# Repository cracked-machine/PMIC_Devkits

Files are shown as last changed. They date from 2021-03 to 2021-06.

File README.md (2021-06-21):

# <U>STPMIC1 / PF3000 PMIC Dev Board</U>

#### Overview

Dual development board for evaluating two power management integrated circuits (PMIC) chips:

- STMicroElectronics STPMIC1
- NXP PF3000 Power Management ICs.

These are organised into two independantly powered sub-systems.

Each sub-system has a number of external power/signal connectors, along with a list of the jumpers used to configure how those connectors are routed to/from the PMIC chip. The PMICs are configured directly by modifying registers using either a MCU/MPU via the I2C connectors.

Each output has an LED indicator and testpoint. 
_Note_ that the LED will only light if the PMIC output voltage is set above 2V.

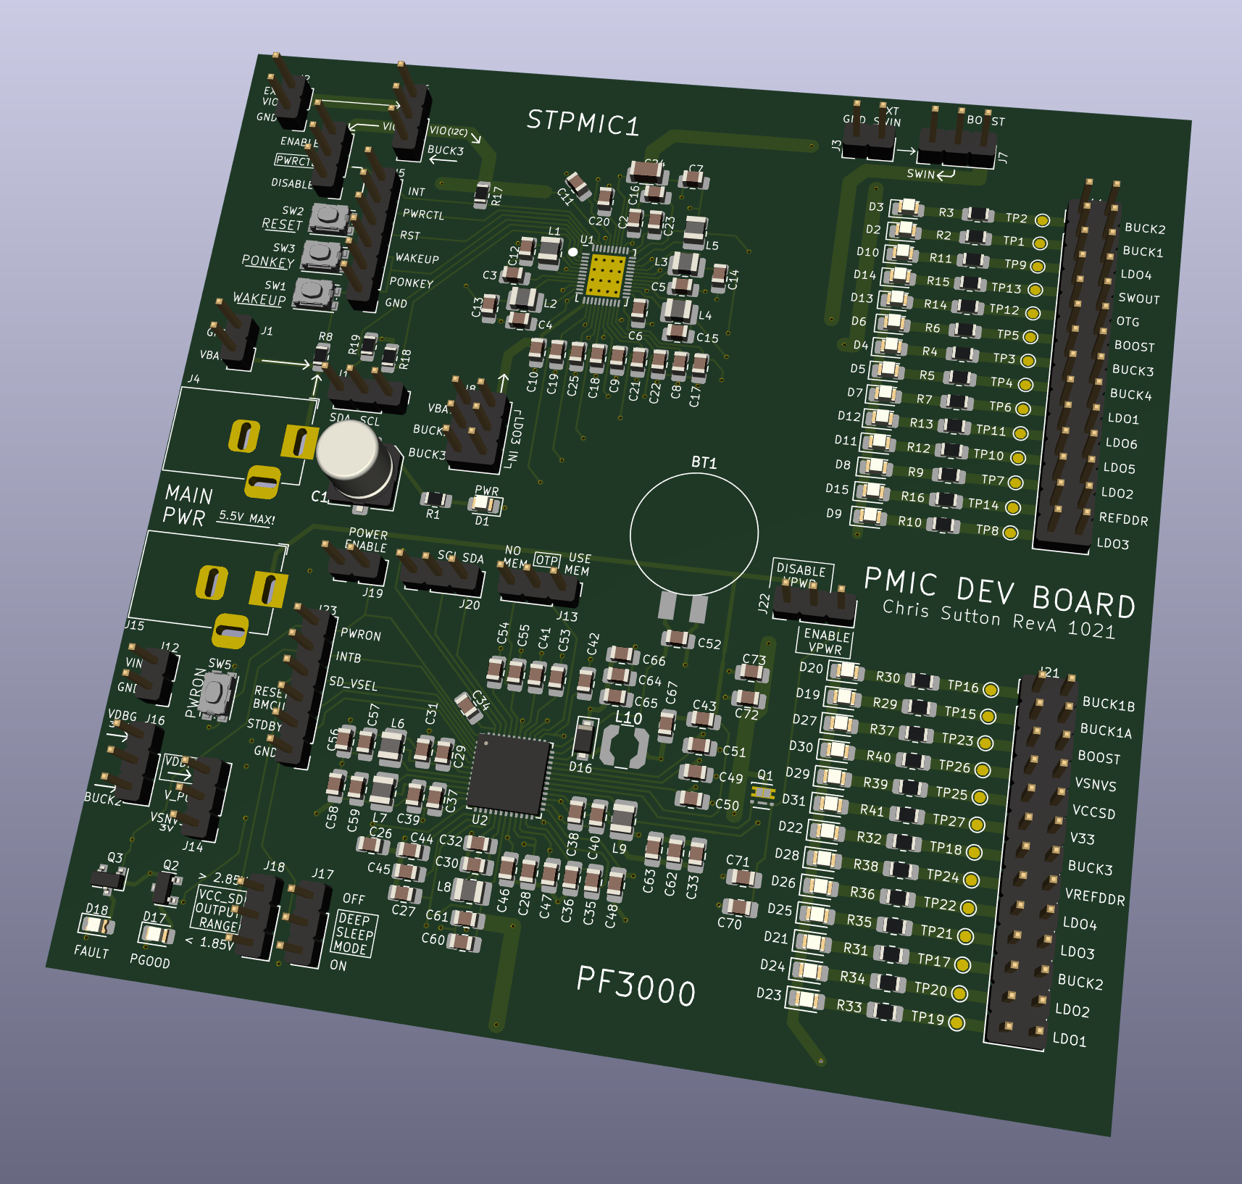
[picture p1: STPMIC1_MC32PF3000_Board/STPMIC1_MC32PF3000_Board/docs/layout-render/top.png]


#### Circuit design notes
The schematic has a separate sheet for both sub-systems. There is one for each chip: 

- __DEV__ - The development board sub-system including power/config connectors.
- __MAIN__ - The individual PMIC including the required passive components for bypassing and SMPS/regulator operation. Designed to be reuseable blocks that can easily be incorproated into an existing design.

| STPMIC1 DEV | STPMIC1 MAIN |
|:---:|:---:|
||

| PF3000 DEV | PF3000 MAIN  |
|:---:|:---:|
|||

#### PCB layout notes
This is a four layer PCB design. The layer stackup is:

1. Signal
2. Ground
3. Small signal and power
4. Small signal and ground

Note the ground planes in layer 2 and 4 are connected.

The _docs_ directory contains:
- RevA gerber build files.
- [Bill of Materials](STPMIC1_MC32PF3000_Board/STPMIC1_MC32PF3000_Board/docs/bom/FULL_STPMIC1_MC32PF3000_Board.csv)
- CPL pick and place files.
- Related vendor application notes, datasheets and reference designs.

Custom symbols and footprints used in this project can be found in the [KicadLibrary](https://github.com/cracked-machine/KicadLibrary) repository.

## <U>PMIC #1: NXP PF300</U>

#### <U>Board connector definitions</U>

| Connector | Description | Comment |
|:---:|:---:|:---|
|J15|Wall adaptor power input|3.7V - 5.5V<br>DC Barrel 2.1mm|
|J12|Battery power input|3.1V - 4.5V<br>2.54mm Header|
|J20|I2C debug|1: Ground<br>2: SCL<br>3: SDA|
|J23|Digital Interface<br>(see datasheet)|1: Ground<br>2: STANDBY<br>3: RESETBMCU<br>4: SD_VSEL<br>5: INTB<br>6: PWRON|
|J21|PF3000 Power Output|Ground:<br>2,4,6,8,10,12,14,16,18,20,22,24,26<br><br>1: SW1B Buck <br>3: SW1A Buck <br>5: SWBST Boost<br>7: VSNVS LDO<br>9: VCCSD LDO<br>11: V33 LDO<br> 13: SW3 Buck<br>15: VREFDDR LDO<br>17: LDO4<br> 19: LDO3<br>21: SW2 Buck<br>23: LDO2<br> 25: LDO1

#### <U>Board jumper and switch definitions</U>

Warning: function of jumpers can be inverted using the registers. See datasheet for details.

| Jumper/Switch | Description| Setting | Comment |
|:---:|:---:|:---:|:---|
|JP1|Q2 Pullup|ON|Force Q2 gate to VDBG rail. <br>Use if PGOOD LED becomes erratic.|
|JP2|Q3 Pullup|ON|Force Q3 to VDBG rail. <br>Use if FAIL LED becomes erratic.|
|J13|OTP|3-2|Load OTP values from memory into OTP registers|
|J13|OTP|2-1|Disable OTP memory and load OTP values from fuses. "Try before buy" mode.|
|J16|I2C Bus Power (VDDIO)|3-2|Power from VDGB. 3.3V|
|J16|I2C Bus Power (VDDIO)|2-1|Power from Buck 2 output. 1.8V|
|J14|Digital Interface Power (V_PU)|3-2|Power from J16 output|
|J14|Digital Interface Power (V_PU)|2-1|Power from VSNVS output (fixed 3V)|
|J17|Standby|3-2|Enter standby mode|
|J17|Standby|2-1|Exit standby mode|
|J18|VCC_SD output range|3-2|1.8V to 1.85V|
|J18|VCC_SD output range|2-1|2.85V to 3.3V|
|J19|Power enable|2-1|IC power output is enabled|
|SW5|Power enable| - | Momentary SPST.<br>IC power output is enabled.
|J22|VPWR override|3-2|VPWR enable. <br>Set when J15 DC connector is powered|
|J22|VPWR override|2-1|VPWR disable. <br>Set when J12 battery power connector is powered.<br>Warning: Shorts J15 to ground!|

## <U>PMIC #2: STMicroelectronics STPMIC1</U>

#### <U>Board connector definitions</U>

| Connector | Description | Comment |
|:---:|:---:|:---|
|J2|External VIO|0.5V to 4.2V.<br>I/O voltage (for all digital signals except WAKEUP and PONKEY)|
|J3|External SWIN|0.5V - 7V.<br>External power source for VSWIN pin.
|J4|Wall adaptor power input|0.5V - 7V.<br>DC Barrel 2.1mm|
|J1|Battery power input|0.5V - 7V.<br>2.54mm Header|
|J10|I2C debug|1: Ground<br>2: SCL<br>3: SDA|
|J5|Digital Interface<br>(see datasheet)|1: Ground<br>2: PONKEY (IN)<br>3: WAKEUP (IN)<br>4: RST (BOTH)<br>5: PWRCTL (IN)<br>6: INT (OUT)|
|J21|STPMIC1 Power Output|Ground:<br>2,4,6,8,10,12,14,16,18,20,22,24,26<br><br>1: Buck2 <br>3: Buck1 <br>5: LDO4<br>7: VSWOUT LDO<br>9: VOTG LDO<br>11: Boost<br> 13: Buck3<br>15: Buck4<br>17: LDO1<br> 19: LDO6<br>21: LDO5<br>23: LDO2<br> 25: VREFDDR LDO<br>27: LDO3|

#### <U>Board jumper and switch definitions</U>

Warning: function of jumpers can be inverted using the registers. See datasheet for details.

| Jumper/Switch | Description| Setting | Comment |
|:---:|:---:|:---:|:---|
|J6|VIO source select|3-2|Power source from Buck3 output|
|J6|VIO source select|2-1|Power source from VIO Ext (J2)|
|J7|VSWIN source select|3-2|Power source from BOOST output|
|J7|VSWIN source select|2-1|Power source from SWIN Ext (J3)|
|J8|LDO3 source select|1-2|Power source from VBAT (J4 or J1)|
|J8|LDO3 source select|3-4|Power source from BUCK2 output|
|J8|LDO3 source select|5-6|Power source from BUCK2 output|
|J9|PWRCTL Pullup/Pulldown|3-2|Pullup from VIO (J6)|
|J9|PWRCTL Pullup/Pulldown|2-1|Pulldown to ground|
|SW1|Wakeup enable| - |Momentary SPST to VBAT|
|SW2|IC Reset| - |Momentary SPST to ground|
|SW3|PONKEY| - |User power on key|

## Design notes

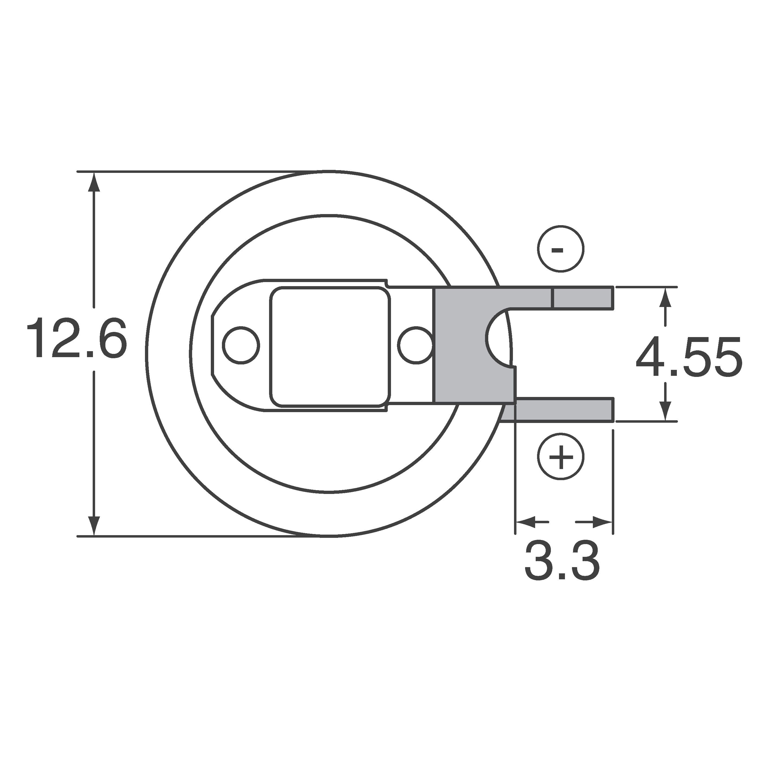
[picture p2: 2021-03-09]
STPMIC1_MC32PF3000_Board/STPMIC1_MC32PF3000_Board/docs/Datasheets/Panasonic - ML-1220 F1BN - 3 Volt 17mAh Lithium.jpg

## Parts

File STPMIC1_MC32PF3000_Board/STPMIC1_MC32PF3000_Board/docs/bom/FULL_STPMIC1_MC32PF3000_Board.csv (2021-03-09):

Reference | Quantity | Value | Footprint | Datasheet | LCSC | MfrNum | Mouser | Type
BT1 | 1 | Battery_Cell | Panasonic_ML_series:ML1220_F1BN | https://docs.rs-online.com/ea3f/0900766b816cd421.pdf | ~ | ML-1220/F1BN | ~ | Panasonic 3V Lithium Manganese Dioxide Button Rechargeable Battery, 17mAh
C1 | 1 | 100uF | Capacitor_SMD:C_Elec_6.3x7.7 | ~ | C127971 | ~ | ~ | ~
C12 C13 C14 C15 C16 C44 C46 C49 C56 C57 C58 C59 C60 C61 C62 C63 C64 C65 C72 C73 | 20 | 22uF | Capacitor_SMD:C_0805_2012Metric_Pad1.18x1.45mm_HandSolder | ~ | C45783 | CL21A226MPQNNNE | ~ | CAP CER 22uF 25V 20% X5R 0805
C2 C11 C17 C18 C20 C21 C22 C23 C43 C45 C47 C50 | 12 | 4.7uF | Capacitor_SMD:C_0805_2012Metric_Pad1.18x1.45mm_HandSolder | ~ | C1779 | ~ | ~
C3 C4 C5 C6 C7 C10 C19 C29 C30 C37 C38 C42 C67 C69 | 14 | 10uF | Capacitor_SMD:C_0805_2012Metric_Pad1.18x1.45mm_HandSolder | ~ | C15850 | ~ | ~
C24 | 1 | 220uF | Capacitor_SMD:C_1206_3216Metric_Pad1.33x1.80mm_HandSolder | ~ | ~ | ~ | ~ | ~
C8 C9 C25 C26 C27 C28 C33 C41 C48 C53 C55 C68 | 12 | 1uF | Capacitor_SMD:C_0805_2012Metric_Pad1.18x1.45mm_HandSolder | ~ | C28323 | ~ | ~
C31 C32 C34 C35 C36 C39 C40 | 7 | 100nF | Capacitor_SMD:C_0805_2012Metric_Pad1.18x1.45mm_HandSolder | ~ | C49678 | ~ | ~ | ~
C51 | 1 | 470nF | Capacitor_SMD:C_0805_2012Metric_Pad1.18x1.45mm_HandSolder | ~ | C13967 | ~ | ~ | ~
C52 C54 | 2 | 220nF | Capacitor_SMD:C_0805_2012Metric_Pad1.18x1.45mm_HandSolder | ~ | C5378 | ~ |  | CAP CER 0.22UF 16V 10% X7R 0402
C66 | 1 | 10nF | Capacitor_SMD:C_0805_2012Metric_Pad1.18x1.45mm_HandSolder | ~ | C1710 | ~ | ~ | ~
C70 C71 | 2 | 47uF | Capacitor_SMD:C_0805_2012Metric_Pad1.18x1.45mm_HandSolder | ~ | C16780 | C2012X5R1A476M125AC | ~ | CAP CER 47uF 10V 20% X5R 0805
D1 D2 D3 D4 D5 D6 D7 D8 D9 D10 D11 D12 D13 D14 D15 D19 D20 D21 D22 D23 D24 D25 D26 D27 D28 D29 D30 D31 | 28 | D | LED_SMD:LED_0805_2012Metric_Pad1.15x1.40mm_HandSolder | ~ | C84256 | ~ | ~ | ~
D16 | 1 | MBR120LSFT3G | Diode_SMD:D_SOD-123F | https://www.mouser.co.uk/datasheet/2/281/product-1023514.pdf | C190475 | ~ | ~ | ~
D17 | 1 | PGOOD | LED_SMD:LED_0805_2012Metric_Pad1.15x1.40mm_HandSolder | ~ | C84256 | ~ | ~ | ~
D18 | 1 | FAULT | LED_SMD:LED_0805_2012Metric_Castellated | ~ | C84256 | ~ | ~ | ~
J6 J7 J9 J10 J13 J14 J16 J17 J18 J20 J22 | 11 | Conn_01x03 | Connector_PinHeader_2.54mm:PinHeader_1x03_P2.54mm_Vertical | ~ | ~ | ~ | ~ | ~
J11 | 1 | Conn_02x14_Odd_Even | Connector_PinHeader_2.54mm:PinHeader_2x14_P2.54mm_Vertical | ~ | ~ | ~ | ~ | ~
J15 | 1 | Barrel_Jack_Switch | Connector_BarrelJack:BarrelJack_Horizontal | ~ | ~ | ~ | ~ | ~
J21 | 1 | Conn_02x13_Odd_Even | Connector_PinHeader_2.54mm:PinHeader_2x13_P2.54mm_Vertical | ~ | ~ | ~ | ~ | ~
J1 J2 J3 J12 J19 | 5 | Conn_01x02 | Connector_PinHeader_2.54mm:PinHeader_1x02_P2.54mm_Vertical | ~ | ~ ~ ~ ~ ~ ~ ~ ~ ~ ~ | ~ | ~ | ~
J4 | 1 | Barrel_Jack | Connector_BarrelJack:BarrelJack_Horizontal | ~ | ~ | ~ | ~ | ~
J5 J23 | 2 | Conn_01x06 | Connector_PinHeader_2.54mm:PinHeader_1x06_P2.54mm_Vertical | ~ | ~ | ~ | ~ | ~
J8 | 1 | Conn_02x03_Odd_Even | Connector_PinHeader_2.54mm:PinHeader_2x03_P2.54mm_Vertical | ~ | ~ | ~ | ~ | ~
JP1 JP2 | 2 | Jumper_NO_Small | Jumper:SolderJumper-2_P1.3mm_Open_RoundedPad1.0x1.5mm | ~ | ~ | ~ | ~ | ~
L1 L2 L3 L4 L5 | 5 | 1uH | Inductor_SMD:L_1008_2520Metric_Pad1.43x2.20mm_HandSolder | https://www.mouser.co.uk/datasheet/2/281/product-1023391.pdf~ | ~ | DFE252012P-1R0M=P2 | 81-DFE252012P-1R0MP2 | IND PWR 1.0μH, 3.5A, 42mΩ 1008
L10 | 1 | 2.2uH | Inductor_SMD:L_Coilcraft_LPS4018 | https://www.mouser.co.uk/datasheet/2/597/lps3015-270734.pdf | ~ | LPS3015-222MRB | 994-LPS4018-222MRC | IND PWR 2.2UH@100KHZ 2.0A 20% SMT
L6 L7 L8 L9 | 4 | 1.5uH | Inductor_SMD:L_1008_2520Metric_Pad1.43x2.20mm_HandSolder | https://www.mouser.co.uk/datasheet/2/281/product-1023514.pdf | ~ | DFE252012P-1R5M=P2 | 81-DFE252012P-1R5MP2 | IND PWR 1.5uH@1MHz 3.5A 20% 1008
NT1 NT2 NT3 NT4 NT5 NT6 NT7 NT8 NT9 NT10 NT11 NT12 NT13 NT14 | 14 | Net-Tie_2 | TinyNetTies:NetTie-2_SMD_Pad0.254mm | ~ | ~ | ~ | ~ | ~
Q1 | 1 | FDMA908PZ | Package_TO_SOT_SMD:Vishay_PowerPAK_SC70-6L_Single | https://www.mouser.co.uk/datasheet/2/308/FDMA908PZ-D-1807576.pdf | ~ | ~ | 512-FDMA908PZ | PMOS PowerTrench -12V, -12A, 12.5mΩ MicroFET-6
Q2 Q3 | 2 | Q_PMOS_GSD | Package_TO_SOT_SMD:SOT-23 | https://www.onsemi.com/pdf/datasheet/ntr1p02t1-d.pdf | ~ | NTR1P02LT3G | 863-NTR1P02LT1G | ~
R1 R2 R3 R4 R5 R6 R7 R8 R9 R10 R11 R12 R13 R14 R15 R16 R18 R19 R27 R28 R29 R30 R31 R32 R33 R34 R35 R36 R37 R38 R39 R40 R41 | 33 | 2K2 | Resistor_SMD:R_0805_2012Metric_Pad1.20x1.40mm_HandSolder | ~ | C17520 | ~ | ~ | ~
R17 | 1 | 10K | Resistor_SMD:R_0805_2012Metric_Pad1.20x1.40mm_HandSolder | ~ | C17414 | ~ | ~ | ~
R20 R21 | 2 | 4K7 | Resistor_SMD:R_0805_2012Metric_Pad1.20x1.40mm_HandSolder | ~ | C17414 | ~ | ~ | ~
R22 R23 R24 R25 R26 | 5 | 100K | Resistor_SMD:R_0805_2012Metric_Pad1.20x1.40mm_HandSolder | ~ | C17407 | ~ | ~ | ~
SW1 SW2 SW3 SW5 | 4 | SW_SPST | Button_Switch_SMD:SW_Push_1P1T_NO_CK_KMR2 | https://docs.rs-online.com/fe48/0900766b815a8e8e.pdf | ~ | KMR221NGLFS | 611-KMR221NGLFS | Tactile Microminiature SMT Top Actuated
TP1 TP2 TP3 TP4 TP5 TP6 TP7 TP8 TP9 TP10 TP11 TP12 TP13 TP14 TP15 TP16 TP17 TP18 TP19 TP20 TP21 TP22 TP23 TP24 TP25 TP26 TP27 | 27 | TestPoint | TestPoint:TestPoint_Pad_D1.0mm | ~ | ~ | ~ | ~ | ~
U1 | 1 | STPMIC1 | STPMIC1:WQFN-44L_EP_5x6_Pitch0.4mm | https://www.mouser.co.uk/datasheet/2/389/stpmic1-1621294.pdf |  | STPMIC1APQR | 511-STPMIC1APQR | ~
U2 | 1 | PF3000 | Package_DFN_QFN:QFN-48-1EP_7x7mm_P0.5mm_EP5.3x5.3mm_ThermalVias | https://www.nxp.com/docs/en/data-sheet/PF3000.pdf |  | MC32PF3000A8EP | 841-MC32PF3000A8EP | ~
U3 | 1 | SE8233X2 | Package_TO_SOT_SMD:SOT-23 | https://datasheet.lcsc.com/szlcsc/1912111437_Seaward-Elec-SE8233X2_C437587.pdf | C437587 | SE8233X2 | ~ | ~

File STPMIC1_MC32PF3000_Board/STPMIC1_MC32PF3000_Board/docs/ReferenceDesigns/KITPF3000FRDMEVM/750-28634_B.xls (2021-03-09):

Level | Number | Subclass | Description | Families | Part Category | Lifecycle Phase | Rev | Rev Release Date | Rev Incorp Date | Effectivity Start Date | Exclude from Rollup | Compliance Calculated Date | Overall Compliance | Shippable Item | N/A | Commodity | Sites | BOM.Rev | BOM.Item Description | BOM.Alt Num | BOM.Find Num | BOM.Priority | BOM.Qty | BOM.Sites | BOM.Pack Slip | BOM.Ref Des | BOM.Item Type | BOM.Lifecycle Phase | BOM.Assembly Flow ID | BOM.Customer Code | BOM.BOM Notes | Manufacturers.Mfr Name ~ Location | Manufacturers.Mfr. Part Number | Manufacturers.Mfr Part Status | Manufacturers.Preferred Status | Manufacturers.Summary Compliance | Manufacturers.Mfr. Part Description | Manufacturers.Sites | Manufacturers.Reference Notes | Manufacturers.Expiry Date | Manufacturers.Supplier | Manufacturers.Qual Status
0 | 750-28634 | Part | SUB ASSEMBLY, SCHEMATIC PARTS, 700-28634, KITPF3000FRDMEVM | Analog |  | Production | B ECO56462 | 02/20/2015 06:15:38 PM CST |  |  | No | 05/08/2015 09:00:52 PM CDT | Non-Compliant | No |  |  | 5150~Freescale HW/SW MFG Austin~DEVTOOL;5154~Freescale HW/SW MFG Israel~DEVTOOL;5151~Freescale HW/SW MFG HKG~DEVTOOL;5155~Freescale HW/SW MFG HKG DWG~DEVTOOL
1 | 150-30114 | CADPart | CAP CER 0.01UF 50V 10% X7R 0402 | Special Customer Request | Component, Procured by Contract House | Production | A1 MCO34749 | 08/07/2014 06:50:43 PM CDT |  |  | No | 05/08/2015 09:00:52 PM CDT | Missing Info | No |  | Capacitor | 5150~Freescale HW/SW MFG Austin~DEVTOOL;5154~Freescale HW/SW MFG Israel~DEVTOOL;5151~Freescale HW/SW MFG HKG~DEVTOOL;5155~Freescale HW/SW MFG HKG DWG~DEVTOOL | A1 MCO34749 | CAP CER 0.01UF 50V 10% X7R 0402 | 1 | 0 | 1 | 1 |  | No | C38 | CADPart | Production |  |  |  | VENKEL COMPANY | C0402X7R500-103KNE | ROHS Active | Alternate | Missing Info | CAP CER 0.01UF 50V 10% X7R 0402
 |  |  |  |  |  |  |  |  |  |  |  |  |  |  |  |  |  |  |  |  |  |  |  |  |  |  |  |  |  |  |  | SKYMOS | 0402B103K500NT | ROHS Active | Alternate | Missing Info | CAP CER 0.01UF 50V 10% X7R 0402
 |  |  |  |  |  |  |  |  |  |  |  |  |  |  |  |  |  |  |  |  |  |  |  |  |  |  |  |  |  |  |  | WALSIN TECHNOLOGY CORP. | 0402B103K500CT | Active | Alternate | Missing Info | CAP CER 0.01UF 50V 10% X7R 0402
 |  |  |  |  |  |  |  |  |  |  |  |  |  |  |  |  |  |  |  |  |  |  |  |  |  |  |  |  |  |  |  | MURATA | GRM155R71H103KA88D | ROHS Active | Alternate | Missing Info | CAP CER 0.01UF 50V 10% X7R 0402
 |  |  |  |  |  |  |  |  |  |  |  |  |  |  |  |  |  |  |  |  |  |  |  |  |  |  |  |  |  |  |  | SAMSUNG | CL05B103KB5NNNC | Active | Alternate | Missing Info | CAP CER 0.01UF 50V 10% X7R 0402
 |  |  |  |  |  |  |  |  |  |  |  |  |  |  |  |  |  |  |  |  |  |  |  |  |  |  |  |  |  |  |  | KEMET | C0402C103K5RACTU | ROHS Active | Alternate | Missing Info | CAP CER 0.01UF 50V 10% X7R 0402
 |  |  |  |  |  |  |  |  |  |  |  |  |  |  |  |  |  |  |  |  |  |  |  |  |  |  |  |  |  |  |  | KEMET | C0402C103K5RAC | Active | Alternate | Missing Info | CAP CER 0.01UF 50V 10% X7R 0402
1 | 150-30124 | CADPart | CAP CER 1.0UF 16V 10% X5R 0603 |  | Component, Procured by Contract House | Production | A MCO34884 | 08/10/2014 07:28:07 PM CDT |  |  | No | 05/08/2015 09:00:52 PM CDT | Missing Info | No |  | Capacitor | 5150~Freescale HW/SW MFG Austin~DEVTOOL;5154~Freescale HW/SW MFG Israel~DEVTOOL;5151~Freescale HW/SW MFG HKG~DEVTOOL;5155~Freescale HW/SW MFG HKG DWG~DEVTOOL | A MCO34884 | CAP CER 1.0UF 16V 10% X5R 0603 | 1 | 0 | 1 | 2 |  | No | C3,C6 | CADPart | Production |  |  |  | TDK | C1608X5R1C105K | ROHS Active | Preferred | Missing Info | CAP CER 1.0UF 16V 10% X5R 0603
1 | 150-75283 | CADPart | CAP CER 10UF 16V 10% X5R 0805 |  | Component, Procured by Contract House | Production | A MCO34828 | 08/08/2014 04:04:37 PM CDT |  |  | No | 05/11/2015 09:06:56 AM CDT | Missing Info | No |  | Capacitor | 5150~Freescale HW/SW MFG Austin~DEVTOOL;5154~Freescale HW/SW MFG Israel~DEVTOOL;5151~Freescale HW/SW MFG HKG~DEVTOOL;5155~Freescale HW/SW MFG HKG DWG~DEVTOOL | A MCO34828 | CAP CER 10UF 16V 10% X5R 0805 | 1 | 0 | 1 | 3 |  | No | C64,C66,C69 | CADPart | Production |  |  |  | WALSIN TECHNOLOGY CORP. | 0805X106K160CT | ROHS Active | Alternate | Missing Info | CAP CER 10UF 16V 10% X5R 0805
 |  |  |  |  |  |  |  |  |  |  |  |  |  |  |  |  |  |  |  |  |  |  |  |  |  |  |  |  |  |  |  | TDK | C2012X5R1C106K/1.25 | Active | Alternate | Missing Info | CAP CER 10UF 16V 10% X5R 0805
 |  |  |  |  |  |  |  |  |  |  |  |  |  |  |  |  |  |  |  |  |  |  |  |  |  |  |  |  |  |  |  | KYOCERA | CM21X5R106K16AT | Active | Alternate | Missing Info | CAP CER 10UF 16V 10% X5R 0805
 |  |  |  |  |  |  |  |  |  |  |  |  |  |  |  |  |  |  |  |  |  |  |  |  |  |  |  |  |  |  |  | AVX | 0805YD106KAT2A | ROHS Active | Preferred | Missing Info | CAP CER 10UF 16V 10% X5R 0805
 |  |  |  |  |  |  |  |  |  |  |  |  |  |  |  |  |  |  |  |  |  |  |  |  |  |  |  |  |  |  |  | KEMET | C0805C106K4PAC | ROHS Active | Alternate | Missing Info | CAP CER 10UF 16V 10% X5R 0805
 |  |  |  |  |  |  |  |  |  |  |  |  |  |  |  |  |  |  |  |  |  |  |  |  |  |  |  |  |  |  |  | MURATA | GRM21BR61C106KE15L | ROHS Active | Alternate | Missing Info | CAP CER 10UF 16V 10% X5R 0805
 |  |  |  |  |  |  |  |  |  |  |  |  |  |  |  |  |  |  |  |  |  |  |  |  |  |  |  |  |  |  |  | YAGEO AMERICA | CC0805KKX5R7BB106 | ROHS Active | Alternate | Missing Info | CAP CER 10UF 16V 10% X5R 0805
1 | 150-75599 | CADPart | CAP CER 0.1UF 25V 10% X7R 0805 | Special Customer Request | Component, Procured by Contract House | Production | A1 MCO34739 | 08/07/2014 06:31:13 PM CDT |  |  | No | 05/08/2015 09:00:52 PM CDT | Missing Info | No |  | Capacitor | 5150~Freescale HW/SW MFG Austin~DEVTOOL;5154~Freescale HW/SW MFG Israel~DEVTOOL;5151~Freescale HW/SW MFG HKG~DEVTOOL;5155~Freescale HW/SW MFG HKG DWG~DEVTOOL | A1 MCO34739 | CAP CER 0.1UF 25V 10% X7R 0805 | 1 | 0 | 1 | 5 |  | No | C63,C65,C67,C68,C70 | CADPart | Production |  |  |  | MURATA | GRM21BR71E104KA01L | Active | Preferred | Missing Info | CAP CER 0.1UF 25V 10% X7R 0805
 |  |  |  |  |  |  |  |  |  |  |  |  |  |  |  |  |  |  |  |  |  |  |  |  |  |  |  |  |  |  |  | SMEC | MCCC104K2NRTF | ROHS Active | Alternate | Missing Info | CAP CER 0.1UF 25V 10% X7R 0805
1 | 150-75634 | CADPart | CAP CER 0.1UF 10V 10% X5R 0402 | Special Customer Request | Component, Procured by Contract House | Production | A1 MCO35970 | 11/11/2014 11:28:38 PM CST |  |  | No | 05/08/2015 09:00:52 PM CDT | Missing Info |  |  | Capacitor | 5150~Freescale HW/SW MFG Austin~DEVTOOL;5154~Freescale HW/SW MFG Israel~DEVTOOL;5151~Freescale HW/SW MFG HKG~DEVTOOL;5155~Freescale HW/SW MFG HKG DWG~DEVTOOL | A1 MCO35970 | CAP CER 0.1UF 10V 10% X5R 0402 | 1 | 0 | 1 | 13 |  | No | C10,C22,C28,C33,C34,C35,C46,C47,C48,C49,C54,C56,C60 | CADPart | Production |  |  |  | TDK | C1005X5R1A104KB | Active | Alternate | Missing Info | CAP CER 0.1UF 10V 10% X5R 0402
 |  |  |  |  |  |  |  |  |  |  |  |  |  |  |  |  |  |  |  |  |  |  |  |  |  |  |  |  |  |  |  | KEMET | C0402C104K8PAC | ROHS Active | Preferred | Missing Info | CAP CER 0.1UF 10V 10% X5R 0402
 |  |  |  |  |  |  |  |  |  |  |  |  |  |  |  |  |  |  |  |  |  |  |  |  |  |  |  |  |  |  |  | AVX | 0402ZD104KAT2A | ROHS Active | Alternate | Missing Info | CAP CER 0.1UF 10V 10% X5R 0402
 |  |  |  |  |  |  |  |  |  |  |  |  |  |  |  |  |  |  |  |  |  |  |  |  |  |  |  |  |  |  |  | MURATA | GRM155R61A104KA01D | ROHS Active | Alternate | Missing Info | CAP CER 0.1UF 10V 10% X5R 0402
 |  |  |  |  |  |  |  |  |  |  |  |  |  |  |  |  |  |  |  |  |  |  |  |  |  |  |  |  |  |  |  | JOHANSON DIELECTRICS | 100R07X104KV4T | ROHS Active | Alternate | Missing Info | CAP CER 0.1UF 10V 10% X5R 0402
 |  |  |  |  |  |  |  |  |  |  |  |  |  |  |  |  |  |  |  |  |  |  |  |  |  |  |  |  |  |  |  | YAGEO AMERICA | CC0402KRX5R6BB104 | Active | Alternate | Missing Info | CAP CER 0.1UF 10V 10% X5R 0402 |  |  |  |  | Unqualified
1 | 150-75772 | CADPart | CAP CER 1.0UF 10V 10% X5R 0402 | Special Customer Request | Component, Procured by Contract House | Production | A1 MCO36545 | 04/09/2015 12:38:20 AM CDT |  |  | No | 05/08/2015 09:00:52 PM CDT | Missing Info | No |  | Capacitor | 5150~Freescale HW/SW MFG Austin~DEVTOOL;5154~Freescale HW/SW MFG Israel~DEVTOOL;5151~Freescale HW/SW MFG HKG~DEVTOOL;5155~Freescale HW/SW MFG HKG DWG~DEVTOOL | A1 MCO36545 | CAP CER 1.0UF 10V 10% X5R 0402 | 1 | 0 | 1 | 8 |  | No | C9,C11,C12,C21,C25,C26,C29,C59 | CADPart | Production |  |  |  | WALSIN TECHNOLOGY CORP. | 0402X105K100CT | Active | Alternate | Missing Info | CAP CER 1.0UF 10V 10% X5R 0402
 |  |  |  |  |  |  |  |  |  |  |  |  |  |  |  |  |  |  |  |  |  |  |  |  |  |  |  |  |  |  |  | CAL-CHIP | GMC04X5R105K10NT-LF | Active | Alternate | Missing Info | CAP CER 1.0UF 10V 10% X5R 0402
 |  |  |  |  |  |  |  |  |  |  |  |  |  |  |  |  |  |  |  |  |  |  |  |  |  |  |  |  |  |  |  | MURATA | GRM155R61A105KE15D | ROHS Active | Alternate | Missing Info | CAP CER 1.0UF 10V 10% X5R 0402
 |  |  |  |  |  |  |  |  |  |  |  |  |  |  |  |  |  |  |  |  |  |  |  |  |  |  |  |  |  |  |  | YAGEO AMERICA | CC0402KRX5R6BB105 | ROHS Active | Alternate | Missing Info | CAP CER 1uF 10V 10% X5R 0402
 |  |  |  |  |  |  |  |  |  |  |  |  |  |  |  |  |  |  |  |  |  |  |  |  |  |  |  |  |  |  |  | AVX | 0402ZD105KAT2A | Active | Preferred | Missing Info | CAP CER 1.0UF 10V 10% X5R 0402 |  |  |  |  | Unqualified
1 | 150-76792 | CADPart | CAP CER 2.2UF 6.3V 20% X5R 0402 | Special Customer Request | Component, Procured by Contract House | Production | A1 MCO34902 | 08/11/2014 03:24:05 AM CDT |  |  | No | 05/11/2015 09:06:56 AM CDT | Non-Compliant | No |  | Capacitor | 5150~Freescale HW/SW MFG Austin~DEVTOOL;5154~Freescale HW/SW MFG Israel~DEVTOOL;5151~Freescale HW/SW MFG HKG~DEVTOOL;5155~Freescale HW/SW MFG HKG DWG~DEVTOOL | A1 MCO34902 | CAP CER 2.2UF 6.3V 20% X5R 0402 | 1 | 0 | 1 | 3 |  | No | C24,C30,C42 | CADPart | Production |  |  |  | WALSIN TECHNOLOGY CORP. | 0402X225M6R3CT | ROHS Active | Alternate | Non-Compliant | CAP CER 2.2UF 6.3V 20% X5R 0402
 |  |  |  |  |  |  |  |  |  |  |  |  |  |  |  |  |  |  |  |  |  |  |  |  |  |  |  |  |  |  |  | KEMET | C0402C225M9PACTU | ROHS Active | Preferred | Missing Info | CAP CER 2.2UF 6.3V 20% X5R 0402
 |  |  |  |  |  |  |  |  |  |  |  |  |  |  |  |  |  |  |  |  |  |  |  |  |  |  |  |  |  |  |  | MURATA | GRM155R60J225ME15D | Active | Alternate | Missing Info | CAP CER 2.2UF 6.3V 20% X5R 0402
1 | 150-77975 | CADPart | CAP CER 4.7UF 10V 10% X5R 0603 | Special Customer Request | Component, Procured by Contract House | Production | A1 MCO34806 | 08/11/2014 08:58:53 AM CDT |  |  | No | 05/08/2015 09:00:52 PM CDT | Missing Info | No |  | Capacitor | 5150~Freescale HW/SW MFG Austin~DEVTOOL;5154~Freescale HW/SW MFG Israel~DEVTOOL;5151~Freescale HW/SW MFG HKG~DEVTOOL;5155~Freescale HW/SW MFG HKG DWG~DEVTOOL | A1 MCO34806 | CAP CER 4.7UF 10V 10% X5R 0603 | 1 | 0 | 1 | 1 |  | No | C43 | CADPart | Production |  |  |  | MURATA | GRM188R61A475KE15D | ROHS Active | Alternate | Missing Info | CAP CER 4.7uF 10V 10% X5R 0603
 |  |  |  |  |  |  |  |  |  |  |  |  |  |  |  |  |  |  |  |  |  |  |  |  |  |  |  |  |  |  |  | TAIYO YUDEN | LMK107BJ475KA-T | ROHS Active | Preferred | Missing Info | CAP CER 4.7uF 10V 10% X5R 0603
1 | 150-78463 | CADPart | CAP CER 4.7UF 6.3V 20% X5R 0402 | Special Customer Request | Component, Procured by Contract House | Production | A1 MCO36323 | 02/11/2015 03:04:05 AM CST |  |  | No | 05/08/2015 09:00:52 PM CDT | Missing Info | No |  | Capacitor | 5150~Freescale HW/SW MFG Austin~DEVTOOL;5154~Freescale HW/SW MFG Israel~DEVTOOL;5151~Freescale HW/SW MFG HKG~DEVTOOL;5155~Freescale HW/SW MFG HKG DWG~DEVTOOL | A1 MCO36323 | CAP CER 4.7UF 6.3V 20% X5R 0402 | 1 | 0 | 1 | 3 |  | No | C16,C27,C58 | CADPart | Production |  |  |  | MURATA | GRM155R60J475ME47D | Active | Alternate | Missing Info | CAP CER 4.7UF 6.3V 20% X5R 0402 |  |  |  |  | Unqualified
 |  |  |  |  |  |  |  |  |  |  |  |  |  |  |  |  |  |  |  |  |  |  |  |  |  |  |  |  |  |  |  | TDK | C1005X5R0J475M | Active Disqualified | Disqualified | Missing Info | CAP CER 4.7UF 6.3V 20% X5R 0402
 |  |  |  |  |  |  |  |  |  |  |  |  |  |  |  |  |  |  |  |  |  |  |  |  |  |  |  |  |  |  |  | VENKEL COMPANY | C0402X5R6R3-475MNP | Active | Alternate | Missing Info | CAP CER 4.7UF 6.3V 20% X5R 0402
 |  |  |  |  |  |  |  |  |  |  |  |  |  |  |  |  |  |  |  |  |  |  |  |  |  |  |  |  |  |  |  | TDK | C1005X5R0J475M050BC | Active | Preferred | Missing Info | CAP CER 4.7UF 6.3V 20% X5R 0402 |  |  |  |  | Unqualified
1 | 150-78501 | CADPart | CAP CER 10UF 10V 10% X7R 0805 |  | Component, Procured by Contract House | Production | A MCO34887 | 08/10/2014 09:17:59 PM CDT |  |  | No | 05/08/2015 09:00:52 PM CDT | Missing Info | No |  | Capacitor | 5150~Freescale HW/SW MFG Austin~DEVTOOL;5154~Freescale HW/SW MFG Israel~DEVTOOL;5151~Freescale HW/SW MFG HKG~DEVTOOL;5155~Freescale HW/SW MFG HKG DWG~DEVTOOL | A MCO34887 | CAP CER 10UF 10V 10% X7R 0805 | 1 | 0 | 1 | 6 |  | No | C7,C37,C41,C50,C53,C55 | CADPart | Production |  |  |  | MURATA | GRM21BR71A106KE51L | ROHS Active | Preferred | Missing Info | CAP CER 10UF 10V 10% X7R 0805
1 | 150-78886 | CADPart | CAP CER 0.22UF 16V 10% X7R 0402 |  | Component, Procured by Contract House | Production | A MCO34880 | 08/10/2014 06:29:19 PM CDT |  |  | No | 05/08/2015 09:00:52 PM CDT | Missing Info | No |  | Capacitor | 5150~Freescale HW/SW MFG Austin~DEVTOOL;5154~Freescale HW/SW MFG Israel~DEVTOOL;5151~Freescale HW/SW MFG HKG~DEVTOOL;5155~Freescale HW/SW MFG HKG DWG~DEVTOOL | A MCO34880 | CAP CER 0.22UF 16V 10% X7R 0402 | 1 | 0 | 1 | 2 |  | No | C8,C13 | CADPart | Production |  |  |  | MURATA | GRM155R71C224KA12D | ROHS Active | Preferred | Missing Info | CAP CER 0.22UF 16V 10% X7R 0402
1 | 150-78887 | CADPart | CAP CER 0.47uF 10V 10% X7R 0402 | Special Customer Request | Component, Procured by Contract House | Production | A1 MCO36408 | 03/03/2015 02:15:16 AM CST |  |  | No | 05/08/2015 09:00:52 PM CDT | Missing Info | No |  | Capacitor | 5150~Freescale HW/SW MFG Austin~DEVTOOL;5154~Freescale HW/SW MFG Israel~DEVTOOL;5151~Freescale HW/SW MFG HKG~DEVTOOL;5155~Freescale HW/SW MFG HKG DWG~DEVTOOL | A1 MCO36408 | CAP CER 0.47uF 10V 10% X7R 0402 | 1 | 0 | 1 | 1 |  | No | C15 | CADPart | Production |  |  |  | MURATA | GRM155R71A474KE01D | Active | Preferred | Missing Info | CAP CER 0.47uF 10V 10% X7R 0402 |  |  |  |  | Unqualified
 |  |  |  |  |  |  |  |  |  |  |  |  |  |  |  |  |  |  |  |  |  |  |  |  |  |  |  |  |  |  |  | CAL-CHIP | GMC04X7R474K10NT-LF | ROHS Active | Alternate | Missing Info | CAP CER 0.47uF 10V 10% X7R 0402
1 | 150-78979 | CADPart | CAP CER 47uF 10V 20% X5R 0805 |  | Component, Procured by Contract House | Production | A MCO34839 | 08/09/2014 07:08:55 PM CDT |  |  | No | 05/08/2015 09:00:52 PM CDT | Missing Info | No |  | Capacitor | 5150~Freescale HW/SW MFG Austin~DEVTOOL;5154~Freescale HW/SW MFG Israel~DEVTOOL;5151~Freescale HW/SW MFG HKG~DEVTOOL;5155~Freescale HW/SW MFG HKG DWG~DEVTOOL | A MCO34839 | CAP CER 47uF 10V 20% X5R 0805 | 1 | 0 | 1 | 2 |  | No | C1,C2 | CADPart | Production |  |  |  | TDK | C2012X5R1A476M | Active | Preferred | Missing Info | CAP CER 47uF 10V 20% X5R 0805
1 | 150-79304 | CADPart | CAP CER 22uF 25V 20% X5R 0805 |  | Component, Procured by Contract House | Production | A MCO34868 | 08/10/2014 12:33:47 PM CDT |  |  | No | 05/08/2015 09:00:52 PM CDT | Missing Info | No |  | Capacitor | 5150~Freescale HW/SW MFG Austin~DEVTOOL;5154~Freescale HW/SW MFG Israel~DEVTOOL;5151~Freescale HW/SW MFG HKG~DEVTOOL;5155~Freescale HW/SW MFG HKG DWG~DEVTOOL | A MCO34868 | CAP CER 22uF 25V 20% X5R 0805 | 1 | 0 | 1 | 12 |  | No | C4,C5,C14,C17,C18,C19,C20,C23,C31,C32,C36,C39 | CADPart | Production |  |  |  | MURATA | GRM21BR61E226ME44 | Active | Preferred | Missing Info | CAP CER 22uF 25V 20% X5R 0805 |  |  |  |  | Unqualified
1 | 180-77038 | CADPart | IND PWR 2.2UH@100KHZ 2.0A 20% SMT |  | Component, Procured by Contract House | Production | A MCO34748 | 08/07/2014 06:52:35 PM CDT |  |  | No | 05/08/2015 09:00:52 PM CDT | Missing Info | No |  | Inductor | 5150~Freescale HW/SW MFG Austin~DEVTOOL;5154~Freescale HW/SW MFG Israel~DEVTOOL;5151~Freescale HW/SW MFG HKG~DEVTOOL;5155~Freescale HW/SW MFG HKG DWG~DEVTOOL | A MCO34748 | IND PWR 2.2UH@100KHZ 2.0A 20% SMT | 1 | 0 | 1 | 1 |  | No | L1 | CADPart | Production |  |  |  | COILCRAFT | LPS3015-222ML_ | Active | Preferred | Missing Info | IND PWR 2.2UH@100KHZ 2.0A 20% SMT
1 | 180-78293 | CADPart | IND PWR 1.5uH@1MHz 3.5A 20% 2520 |  | Component, Procured by Contract House | Production | A ECO53783 | 10/06/2014 11:53:54 AM CDT |  |  | No | 05/08/2015 09:00:52 PM CDT | Missing Info | No |  | Inductor | 5150~Freescale HW/SW MFG Austin~DEVTOOL;5154~Freescale HW/SW MFG Israel~DEVTOOL;5151~Freescale HW/SW MFG HKG~DEVTOOL;5155~Freescale HW/SW MFG HKG DWG~DEVTOOL | A ECO53783 | IND PWR 1.5uH@1MHz 3.5A 20% 2520 | 1 | 0 | 1 | 4 |  | No | L2,L3,L4,L5 | CADPart | Production |  |  |  | TOKO INC. | DFE252012P-1R5M | Active | Preferred | Missing Info | IND PWR 1.5uH@1MHz 3.5A 20% 2520 |  |  |  |  | Unqualified
1 | 210-30160 | CADPart | HDR 1X3 TH 100MIL SP 340H AU 118L | Special Customer Request | Component, Procured by Contract House | Production | A1 MCO34836 | 08/09/2014 06:24:45 PM CDT |  |  | No | 05/08/2015 09:00:52 PM CDT | Missing Info |  |  | Through-Hole | 5150~Freescale HW/SW MFG Austin~DEVTOOL;5154~Freescale HW/SW MFG Israel~DEVTOOL;5151~Freescale HW/SW MFG HKG~DEVTOOL;5155~Freescale HW/SW MFG HKG DWG~DEVTOOL | A1 MCO34836 | HDR 1X3 TH 100MIL SP 340H AU 118L | 1 | 0 | 1 | 5 |  | No | J5,J10,J11,J12,J13 | CADPart | Production |  |  |  | Greenconn Corporation | GPHA114-0302A01 | ROHS Active | Alternate | Missing Info | HDR 1X3 TH 100MIL SP 330H AU 118L
 |  |  |  |  |  |  |  |  |  |  |  |  |  |  |  |  |  |  |  |  |  |  |  |  |  |  |  |  |  |  |  | SULLINS ELECTRONICS CORP | PBC03SAAN | Active | Alternate | Missing Info | HDR 1X3 TH 100MIL SP 338H AU 120L
 |  |  |  |  |  |  |  |  |  |  |  |  |  |  |  |  |  |  |  |  |  |  |  |  |  |  |  |  |  |  |  | HARWIN INC | M20-9990345 | ROHS Active | Preferred | Missing Info | HDR 1X3 TH 2.54MM 330H CU
1 | 210-75818 | CADPart | CON1 PWR PLUG RA 5A--430H IN | Special Customer Request | Component, Procured by Contract House | Production | A4 MCO35815 | 10/20/2014 03:37:37 PM CDT |  |  | No | 05/08/2015 09:00:52 PM CDT | Missing Info | No |  | Through-Hole | 5150~Freescale HW/SW MFG Austin~DEVTOOL;5154~Freescale HW/SW MFG Israel~DEVTOOL;5151~Freescale HW/SW MFG HKG~DEVTOOL;5155~Freescale HW/SW MFG HKG DWG~DEVTOOL | A4 MCO35815 | CON1 PWR PLUG RA 5A--430H IN | 1 | 0 | 1 | 1 |  | No | J1 | CADPart | Production |  |  |  | SWITCHCRAFT | RAPC722X | ROHS Active | Preferred | Missing Info | CON 1 PWR PLUG RA TH 5A -- 430H NI
1 | 210-78560 | CADPart | CON 1X2 BANANA RA TH 15.3MM SP 488H AG BLACK 197L |  | Component, Procured by Contract House | Production | A MCO34889 | 08/10/2014 09:44:00 PM CDT |  |  | No | 05/08/2015 09:00:52 PM CDT | Missing Info | No |  | Through-Hole | 5150~Freescale HW/SW MFG Austin~DEVTOOL;5154~Freescale HW/SW MFG Israel~DEVTOOL;5151~Freescale HW/SW MFG HKG~DEVTOOL;5155~Freescale HW/SW MFG HKG DWG~DEVTOOL | A MCO34889 | CON 1X2 BANANA RA TH 15.3MM SP 488H AG BLACK 197L | 1 | 0 | 1 | 1 |  | No | J3 | CADPart | Production |  |  |  | DELTRON EMCON LTD | 571-0100-01 | Active | Preferred | Missing Info | CON 1X2 BANANA RA TH 15.3MM SP 488H AG BLACK 197L
1 | 210-78561 | CADPart | CON 1 BANANA RA TH 15.3MM SP 488H AG RED |  | Component, Procured by Contract House | Production | A MCO34839 | 08/09/2014 07:08:55 PM CDT |  |  | No | 05/08/2015 09:00:52 PM CDT | Missing Info | No |  | Through-Hole | 5150~Freescale HW/SW MFG Austin~DEVTOOL;5154~Freescale HW/SW MFG Israel~DEVTOOL;5151~Freescale HW/SW MFG HKG~DEVTOOL;5155~Freescale HW/SW MFG HKG DWG~DEVTOOL | A MCO34839 | CON 1 BANANA RA TH 15.3MM SP 488H AG RED | 1 | 0 | 1 | 2 |  | No | J2,J4 | CADPart | Production |  |  |  | DELTRON EMCON LTD | 571-0500-01 | Active | Preferred | Missing Info | CON 1 BANANA RA TH 15.3MM SP 488H AG RED
1 | 210-78860 | CADPart | CON 2X8 SKT TH 100MIL SP 335H AU 104L |  | Component, Procured by Contract House | Production | A MCO34849 | 08/09/2014 09:40:16 PM CDT |  |  | No | 05/08/2015 09:00:52 PM CDT | Missing Info | No |  | Through-Hole | 5150~Freescale HW/SW MFG Austin~DEVTOOL;5154~Freescale HW/SW MFG Israel~DEVTOOL;5151~Freescale HW/SW MFG HKG~DEVTOOL;5155~Freescale HW/SW MFG HKG DWG~DEVTOOL | A MCO34849 | CON 2X8 SKT TH 100MIL SP 335H AU 104L | 1 | 0 | 1 | 2 |  | No | J19,J21 | CADPart | Production |  |  |  | SAMTEC | SSW-108-01-S-D | Active | Preferred | Missing Info | CON 2X8 SKT TH 100MIL CTR 335H AU
 |  |  |  |  |  |  |  |  |  |  |  |  |  |  |  |  |  |  |  |  |  |  |  |  |  |  |  |  |  |  |  | SAMTEC | SSW-108-01-G-D | ROHS Active | Alternate | Missing Info | CON 2X8 SKT TH 100MIL SP 335H AU 104L
1 | 210-79454 | CADPart | TEST POINT PC MULTI PURPOSE RED TH | Special Customer Request | Component, Procured by Contract House | Production | A1 MCO34883 | 08/10/2014 07:14:28 PM CDT |  |  | No | 05/08/2015 09:00:52 PM CDT | Missing Info | No |  | Through-Hole | 5150~Freescale HW/SW MFG Austin~DEVTOOL;5154~Freescale HW/SW MFG Israel~DEVTOOL;5151~Freescale HW/SW MFG HKG~DEVTOOL;5155~Freescale HW/SW MFG HKG DWG~DEVTOOL | A1 MCO34883 | TEST POINT PC MULTI PURPOSE RED TH | 1 | 0 | 1 | 8 |  | No | TP11,TP12,TP20,TP24,TP25,TP26,TP29,TP30 | CADPart | Production |  |  |  | KEYSTONE ELECTRONICS | 5010 | ROHS Active | Preferred | Missing Info | TEST POINT PC MULTI PURPOSE RED TH
1 | 210-79515 | CADPart | HDR 1X2 TH 100MIL SP 339H AU 118L | Special Customer Request | Component, Procured by Contract House | Production | A1 MCO35726 | 09/24/2014 01:42:59 AM CDT |  |  | No | 05/08/2015 09:00:52 PM CDT | Missing Info | Yes |  | Through-Hole | 5150~Freescale HW/SW MFG Austin~DEVTOOL;5154~Freescale HW/SW MFG Israel~DEVTOOL;5151~Freescale HW/SW MFG HKG~DEVTOOL;5155~Freescale HW/SW MFG HKG DWG~DEVTOOL | A1 MCO35726 | HDR 1X2 TH 100MIL SP 339H AU 118L | 1 | 0 | 1 | 11 |  | No | J6,J7,J8,J9,J14,J15,J16,J17,J18,J24,J25 | CADPart | Production |  |  |  | Pinrex Enterprise Co., Ltd | 210-91-02GB01 | ROHS Active | Alternate | Missing Info | HDR 1X2 TH 100MIL SP 339H AU 118L
 |  |  |  |  |  |  |  |  |  |  |  |  |  |  |  |  |  |  |  |  |  |  |  |  |  |  |  |  |  |  |  | SULLINS ELECTRONICS CORP | PBC01DAAN | ROHS Active | Preferred | Missing Info | HDR 1X2 TH 100MIL SP 338H AU 120L
1 | 210-80119 | CADPart | CON 2X10 SKT TH 100MIL CTR 340H AU 104L |  | Component, Procured by Contract House | Production | A MCO34898 | 08/11/2014 01:15:38 AM CDT |  |  | No | 05/08/2015 09:00:52 PM CDT | Missing Info | No |  | Through-Hole | 5150~Freescale HW/SW MFG Austin~DEVTOOL;5154~Freescale HW/SW MFG Israel~DEVTOOL;5151~Freescale HW/SW MFG HKG~DEVTOOL;5155~Freescale HW/SW MFG HKG DWG~DEVTOOL | A MCO34898 | CON 2X10 SKT TH 100MIL CTR 340H AU 104L | 1 | 0 | 1 | 1 |  | No | J20 | CADPart | Production |  |  |  | SAMTEC | SSW-110-01-G-D | ROHS Active | Preferred | Missing Info | CON 2X10 SKT TH 100MIL CTR 340H AU 104L
1 | 210-80123 | CADPart | CON 2X6 SKT TH 100MIL CTR 340H AU 104L |  | Component, Procured by Contract House | Production | A MCO34858 | 08/10/2014 09:32:48 AM CDT |  |  | No | 05/08/2015 09:00:52 PM CDT | Missing Info | No |  | Through-Hole | 5150~Freescale HW/SW MFG Austin~DEVTOOL;5154~Freescale HW/SW MFG Israel~DEVTOOL;5151~Freescale HW/SW MFG HKG~DEVTOOL;5155~Freescale HW/SW MFG HKG DWG~DEVTOOL | A MCO34858 | CON 2X6 SKT TH 100MIL CTR 340H AU 104L | 1 | 0 | 1 | 1 |  | No | J22 | CADPart | Production |  |  |  | SAMTEC | SSW-106-01-G-D | Active | Preferred | Missing Info | CON 2X6 SKT TH 100MIL CTR 340H AU 104L
1 | 210-80268 | CADPart | TEST POINT WHITE 70X220 MIL TH |  | Component, Procured by Contract House | Production | A MCO34902 | 08/11/2014 03:24:05 AM CDT |  |  | No | 05/08/2015 09:00:52 PM CDT | Missing Info | No |  | Through-Hole | 5150~Freescale HW/SW MFG Austin~DEVTOOL;5154~Freescale HW/SW MFG Israel~DEVTOOL;5151~Freescale HW/SW MFG HKG~DEVTOOL;5155~Freescale HW/SW MFG HKG DWG~DEVTOOL | A MCO34902 | TEST POINT WHITE 70X220 MIL TH | 1 | 0 | 1 | 11 |  | No | TP6,TP7,TP9,TP13,TP14,TP15,TP16,TP35,TP36,TP41,TP42 | CADPart | Production |  |  |  | KEYSTONE ELECTRONICS | 5007 | Active | Preferred | Missing Info | TEST POINT WHITE 70X220 MIL TH
1 | 211-30043 | CADPart | TEST POINT PAD SIZE 4.7MM X 3.5MM SN | Special Customer Request | Component, Procured by Contract House | Production | A1 MCO34907 | 08/11/2014 04:42:31 AM CDT |  |  | No | 05/08/2015 09:00:52 PM CDT | Missing Info | No |  | Connector | 5150~Freescale HW/SW MFG Austin~DEVTOOL;5154~Freescale HW/SW MFG Israel~DEVTOOL;5151~Freescale HW/SW MFG HKG~DEVTOOL;5155~Freescale HW/SW MFG HKG DWG~DEVTOOL | A1 MCO34907 | TEST POINT PAD SIZE 4.7MM X 3.5MM SN | 1 | 0 | 1 | 4 |  | No | TP1,TP4,TP19,TP22 | CADPart | Production |  |  |  | KEYSTONE ELECTRONICS | 5016 | ROHS Active | Preferred | Missing Info | TEST POINT PAD SIZE 4.7MM X 3.4MM SMT
 |  |  |  |  |  |  |  |  |  |  |  |  |  |  |  |  |  |  |  |  |  |  |  |  |  |  |  |  |  |  |  | COMPONENTS CORPORATION | TP-107-02-T | ROHS Active | Alternate | Missing Info | TEST POINT PAD SIZE 4.7MM X 3.5MM SN
1 | 280-75130 | CADPart | HARDWARE PIN TESTPOINT .072X.186 |  | Component, Procured by Contract House | Production | A MCO34902 | 08/11/2014 03:24:05 AM CDT |  |  | No | 05/08/2015 09:00:52 PM CDT | Missing Info | No |  | Screw | 5150~Freescale HW/SW MFG Austin~DEVTOOL;5154~Freescale HW/SW MFG Israel~DEVTOOL;5151~Freescale HW/SW MFG HKG~DEVTOOL;5155~Freescale HW/SW MFG HKG DWG~DEVTOOL | A MCO34902 | HARDWARE PIN TESTPOINT .072X.186 | 1 | 0 | 1 | 10 |  | No | TP2,TP5,TP18,TP21,TP23,TP27,TP28,TP31,TP37,TP44 | CADPart | Production |  |  |  | Pinrex Enterprise Co., Ltd | 999-60-710004 | ROHS Active | Alternate | Missing Info | HARDWARE PIN TESTPOINT .072X.186
 |  |  |  |  |  |  |  |  |  |  |  |  |  |  |  |  |  |  |  |  |  |  |  |  |  |  |  |  |  |  |  | KEYSTONE ELECTRONICS | 1573-3 | ROHS Active | Preferred | Missing Info | HARDWARE PIN TESTPOINT .072X.186
 |  |  |  |  |  |  |  |  |  |  |  |  |  |  |  |  |  |  |  |  |  |  |  |  |  |  |  |  |  |  |  | CONCORD ELECTRONICS | 10-201-3-04 | ROHS Active | Alternate | Missing Info | HARDWARE PIN TESTPOINT .072X.186
 |  |  |  |  |  |  |  |  |  |  |  |  |  |  |  |  |  |  |  |  |  |  |  |  |  |  |  |  |  |  |  | CONCORD ELECTRONICS | 10-201-3-01 | ROHS Active | Alternate | Missing Info | HARDWARE PIN TESTPOINT .072X.186
1 | 280-75148 | CADPart | TEST POINT PAD 35 MIL SMT, NO PART TO ORDER | Special Customer Request | Component, Procured by Contract House | Production | A1 MCO34846 | 08/09/2014 09:03:25 PM CDT |  |  | No | 05/08/2015 09:00:52 PM CDT | Missing Info | Yes |  | Screw | 5150~Freescale HW/SW MFG Austin~DEVTOOL;5154~Freescale HW/SW MFG Israel~DEVTOOL;5151~Freescale HW/SW MFG HKG~DEVTOOL;5155~Freescale HW/SW MFG HKG DWG~DEVTOOL | A1 MCO34846 | TEST POINT PAD 35 MIL SMT, NO PART TO ORDER | 1 | 0 | 1 | 4 |  | No | TP3,TP8,TP10,TP17 | CADPart | Production
1 | 280-75352 | CADPart | MOUNTING HOLE 0.130 INCH, no part to order | ColdFire | Component, Procured by Contract House | Production | A MCO34832 | 08/08/2014 05:47:32 PM CDT |  |  | No | 05/08/2015 09:00:52 PM CDT | Missing Info | No |  | Screw | 5150~Freescale HW/SW MFG Austin~DEVTOOL;5154~Freescale HW/SW MFG Israel~DEVTOOL;5151~Freescale HW/SW MFG HKG~DEVTOOL;5155~Freescale HW/SW MFG HKG DWG~DEVTOOL | A MCO34832 | MOUNTING HOLE 0.130 INCH, no part to order | 1 | 0 | 1 | 4 |  | No | BH1,BH2,BH3,BH4 | CADPart | Production
1 | 312-77320 | CADPart | IC VREG LDO 3.3V 80MA 6.0V SC82-AB |  | Component, Procured by Contract House | Production | A MCO34864 | 08/10/2014 11:03:40 AM CDT |  |  | No | 05/08/2015 09:00:52 PM CDT | Missing Info | No |  | IC Digital | 5150~Freescale HW/SW MFG Austin~DEVTOOL;5154~Freescale HW/SW MFG Israel~DEVTOOL;5151~Freescale HW/SW MFG HKG~DEVTOOL;5155~Freescale HW/SW MFG HKG DWG~DEVTOOL | A MCO34864 | IC VREG LDO 3.3V 80MA 6.0V SC82-AB | 1 | 0 | 1 | 1 |  | No | U1 | CADPart | Production |  |  |  | ON SEMICONDUCTOR | NCP562SQ33T1G | Active | Preferred | Missing Info | IC VREG LDO 3.3V 80MA 6.0V SC82-AB
1 | 315-79580 | CADPart | IC DAC QUAD 12BIT 2.7-5.5V MSOP10 |  | Component, Procured by Contract House | Production | A MCO36244 | 02/03/2015 02:09:35 PM CST |  |  | No | 05/08/2015 09:00:52 PM CDT | Missing Info | No |  | IC Analog | 5150~Freescale HW/SW MFG Austin~DEVTOOL;5154~Freescale HW/SW MFG Israel~DEVTOOL;5151~Freescale HW/SW MFG HKG~DEVTOOL;5155~Freescale HW/SW MFG HKG DWG~DEVTOOL | A MCO36244 | IC DAC QUAD 12BIT 2.7-5.5V MSOP10 | 1 | 0 | 1 | 1 |  | No | U23 | CADPart | Production |  |  |  | MICROCHIP TECHNOLOGY INC | MCP4728-E/UN | Active | Preferred | Missing Info | IC DAC QUAD 12BIT 2.7-5.5V MSOP10
1 | 315-79652 | CADPart | IC LIN OPAMP DUAL AUTO-ZERO 1.8-5.5V SOIC8 |  | Component, Procured by Contract House | Production | A MCO34831 | 08/08/2014 05:29:23 PM CDT |  |  | No | 05/08/2015 09:00:52 PM CDT | Missing Info | No |  | IC Analog | 5150~Freescale HW/SW MFG Austin~DEVTOOL;5154~Freescale HW/SW MFG Israel~DEVTOOL;5151~Freescale HW/SW MFG HKG~DEVTOOL;5155~Freescale HW/SW MFG HKG DWG~DEVTOOL | A MCO34831 | IC LIN OPAMP DUAL AUTO-ZERO 1.8-5.5V SOIC8 | 1 | 0 | 1 | 2 |  | No | U21,U24 | CADPart | Production |  |  |  | MICROCHIP TECHNOLOGY INC | MCP6V07-E/SN | Active | Preferred | Missing Info | IC LIN OPAMP DUAL AUTO-ZERO 1.8-5.5V SOIC8
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

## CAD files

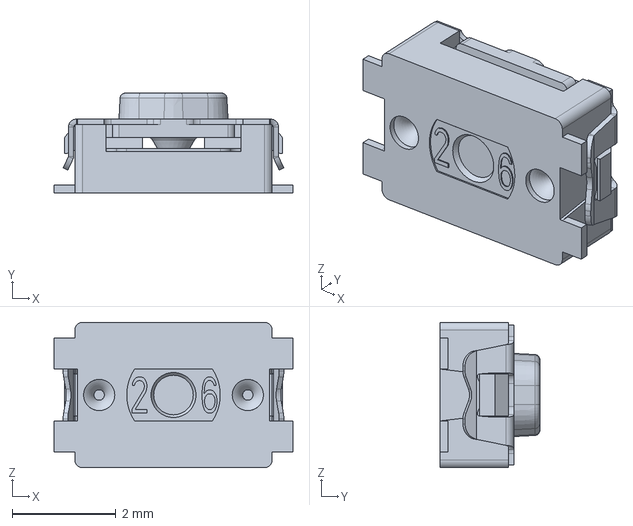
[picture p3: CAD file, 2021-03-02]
STPMIC1_MC32PF3000_Board/STPMIC1_MC32PF3000_Board/docs/STEP/CKCOMPONENTS_KMR231NGULCLFS/KMR231NGULCLFS.stp
4.60 x 1.92 x 2.80 mm

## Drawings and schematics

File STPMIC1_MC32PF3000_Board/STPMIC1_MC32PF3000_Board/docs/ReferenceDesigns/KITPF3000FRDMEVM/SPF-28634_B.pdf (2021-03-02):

VIN | GND | VPWR

### Mounting Holes

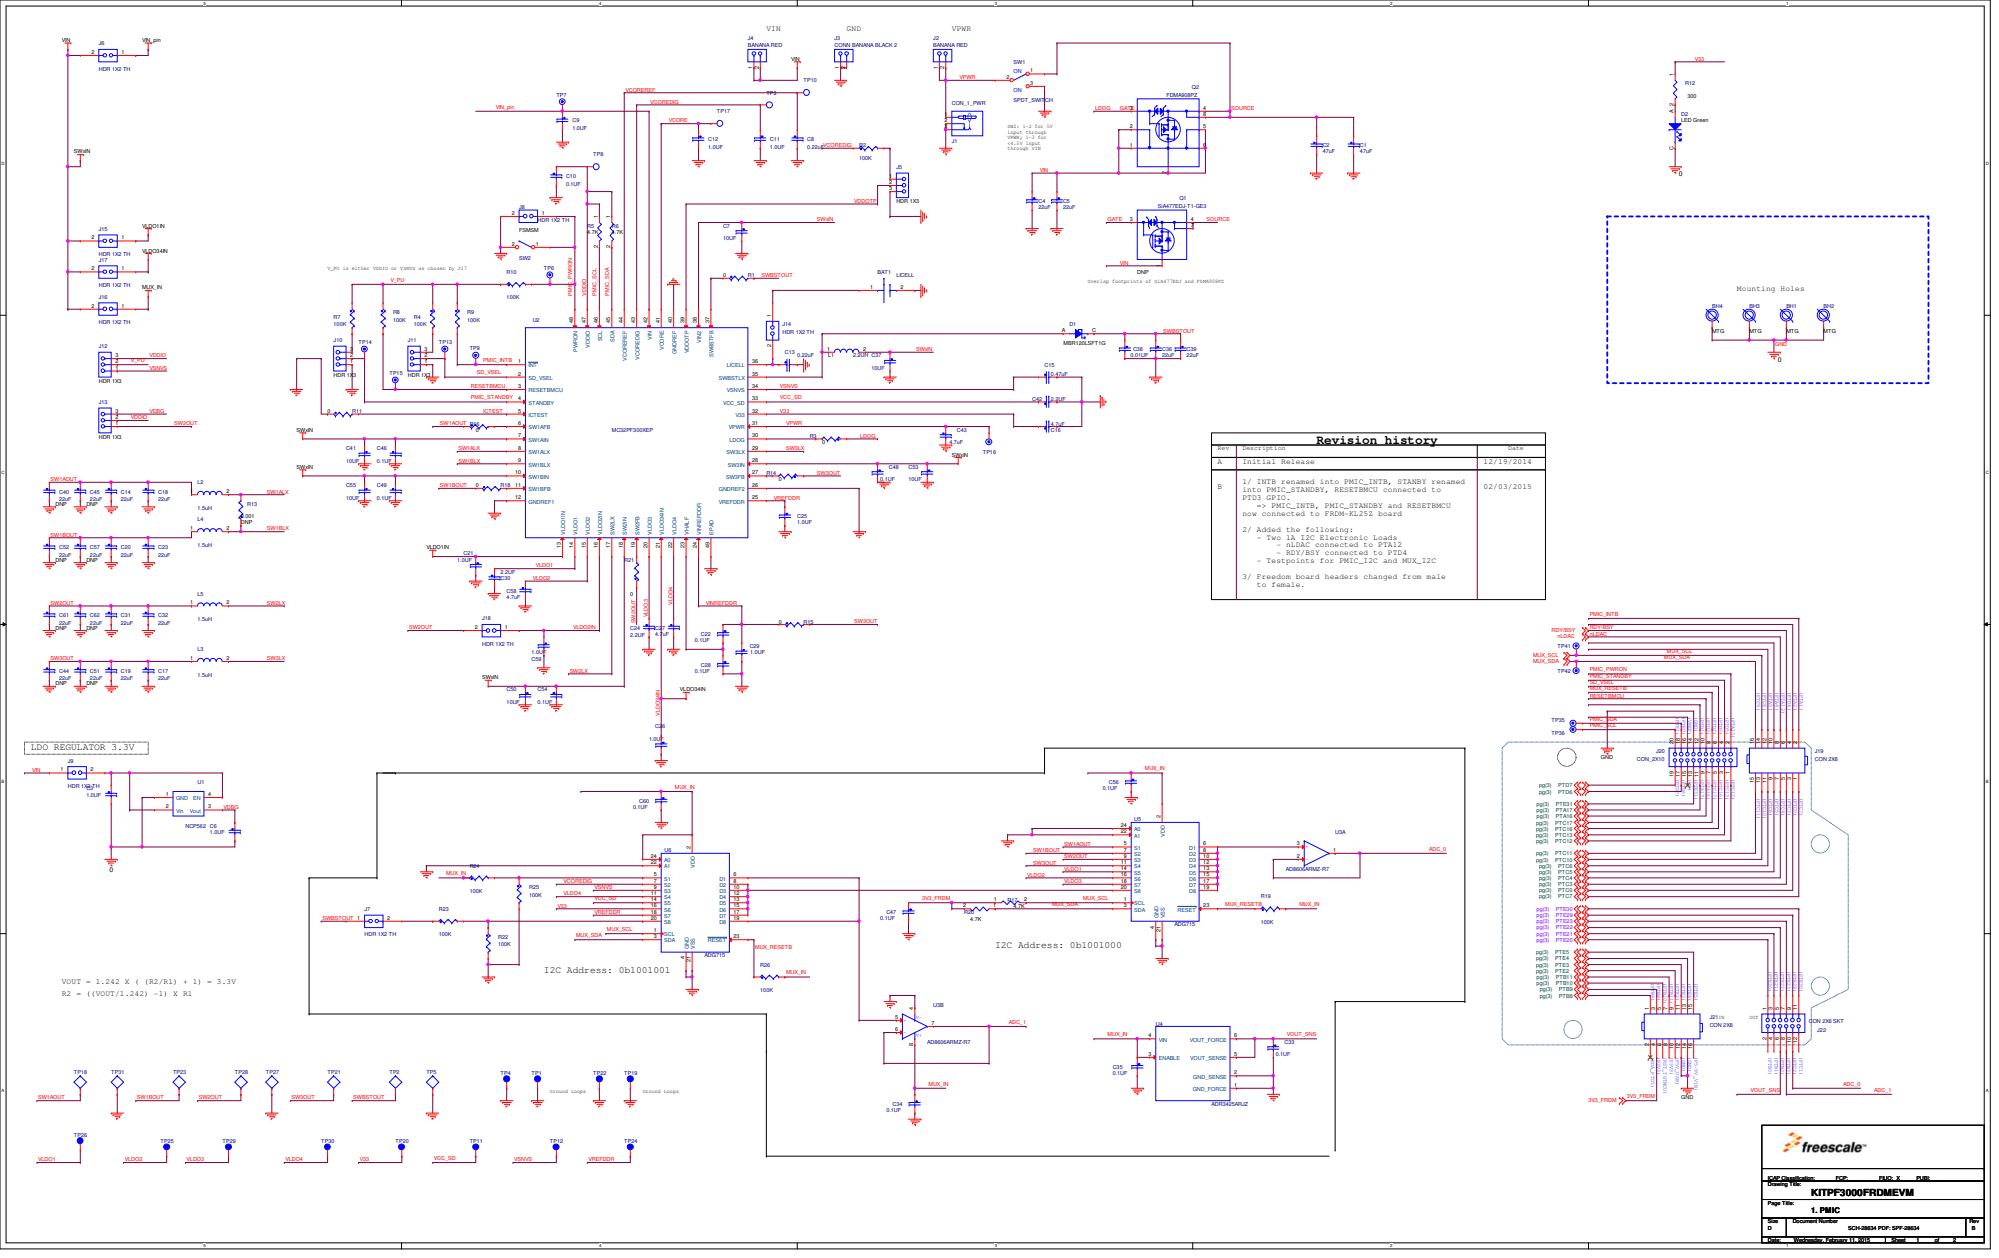
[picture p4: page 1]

V_PU is either VDDIO or VSNVS as chosen by J17

Overlap footprints of SiA477EDJ and FDMA908PZ

1/ INTB renamed into PMIC_INTB, STANBY renamed
into PMIC_STANDBY, RESETBMCU connected to
PTD3 GPIO.
=> PMIC_INTB, PMIC_STANDBY and RESETBMCU
now connected to FRDM-KL25Z board

- nLDAC connected to PTA12
- RDY/BSY connected to PTD4

3/ Freedom board headers changed from male
to female.

5

4

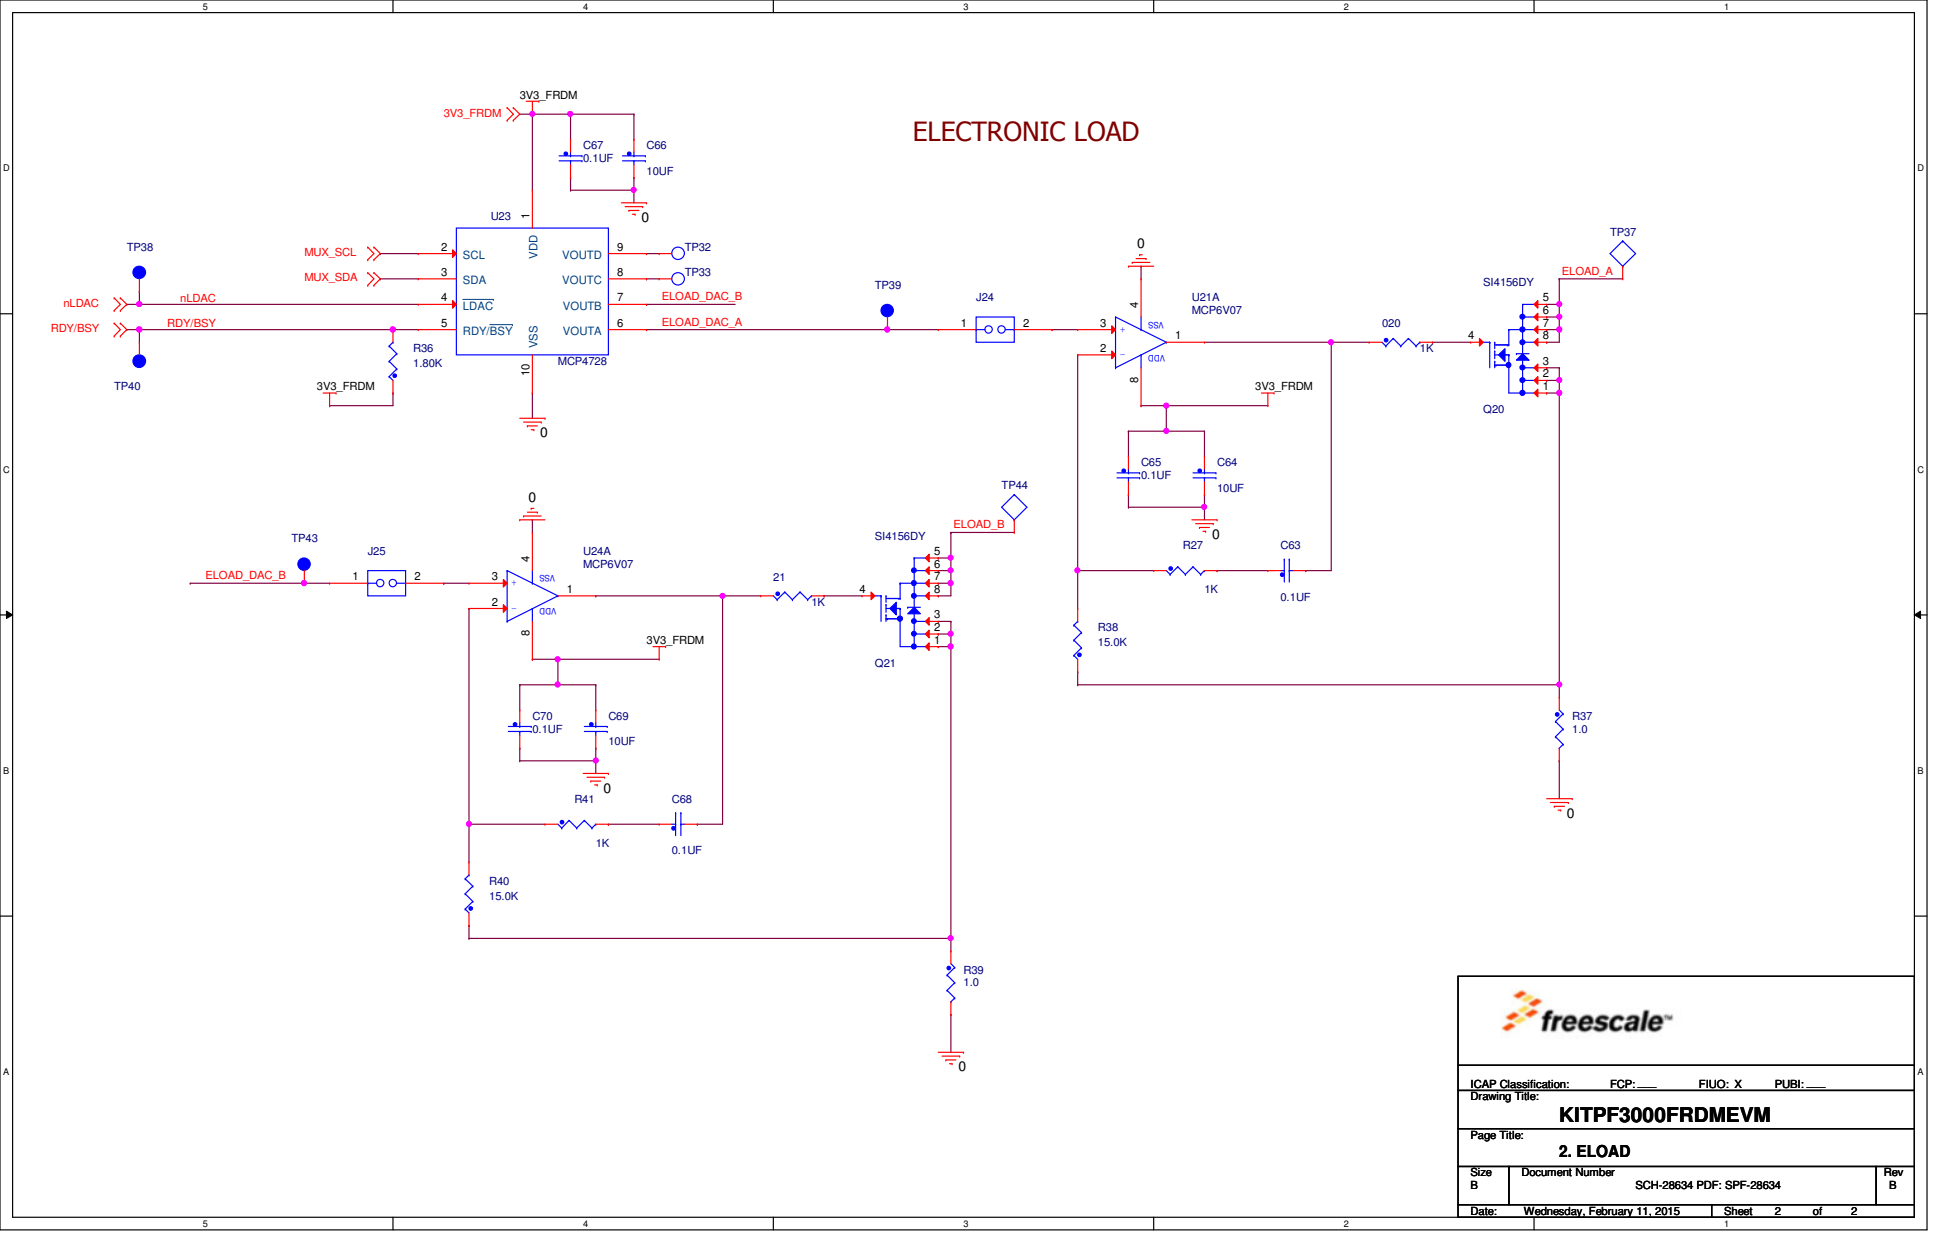
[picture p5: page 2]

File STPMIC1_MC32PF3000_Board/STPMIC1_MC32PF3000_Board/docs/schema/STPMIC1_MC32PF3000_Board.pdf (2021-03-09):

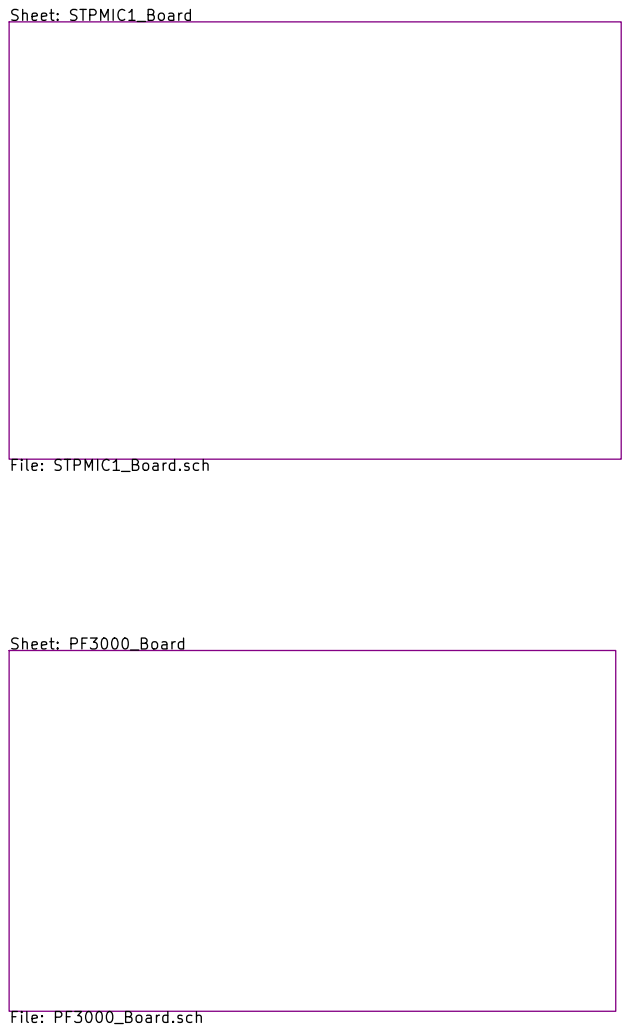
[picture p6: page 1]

Sheet: STPMIC1_Board File: STPMIC1_Board.sch Sheet: PF3000_Board File: PF3000_Board.sch

File: STPMIC1_MC32PF3000_Board.sch Sheet: / Chris Sutton

Id: 1/5 Title: System Overview

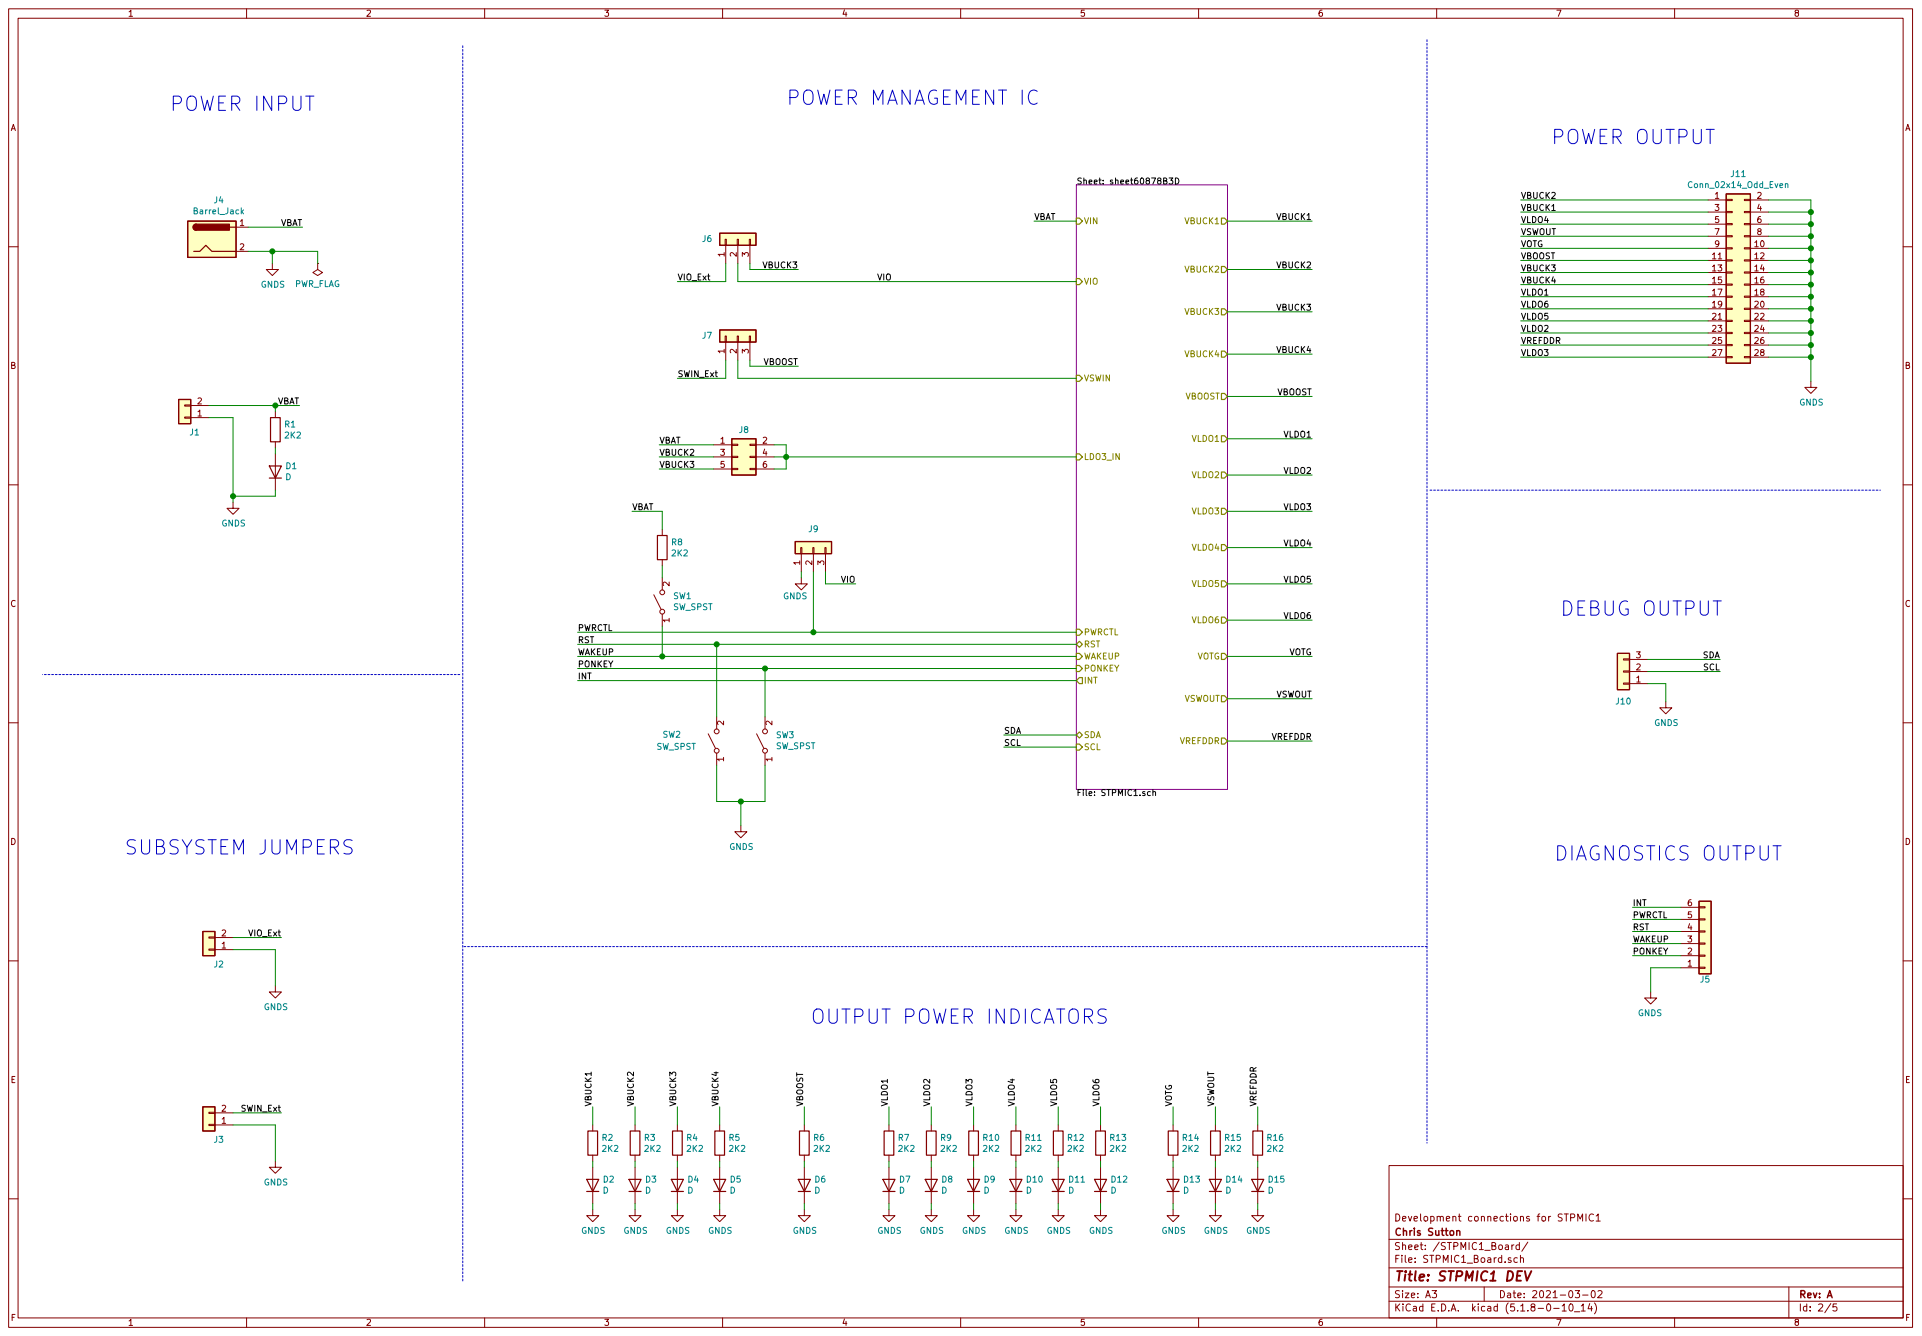
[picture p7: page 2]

Sheet: /STPMIC1_Board/ Chris Sutton Development connections for STPMIC1

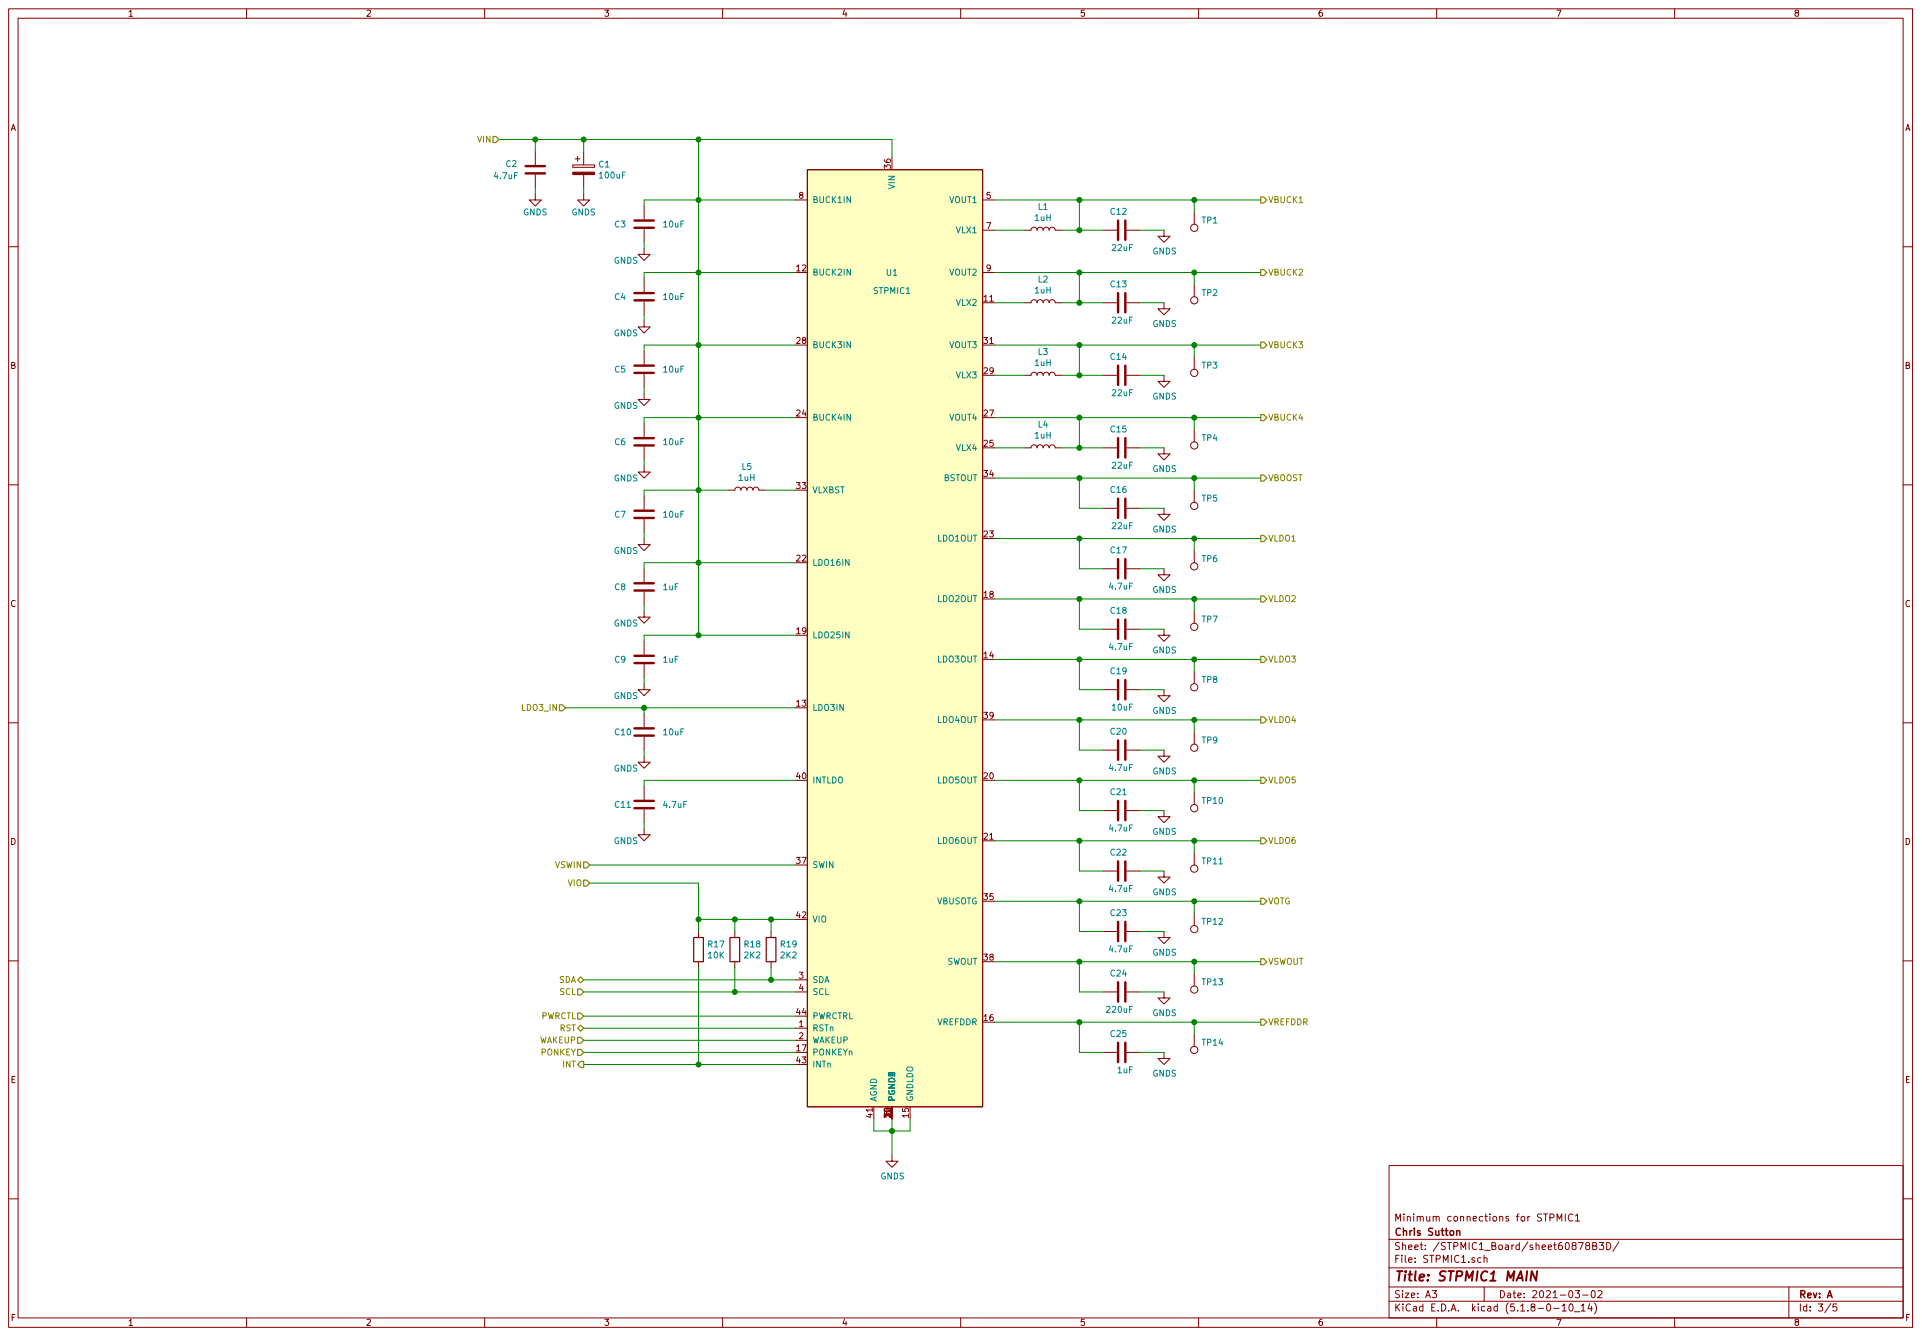
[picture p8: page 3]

TP3 GNDS GNDS GNDS GNDS

GNDS GNDS GNDS

INT PONKEY WAKEUP RST PWRCTL SCL SDA

File: STPMIC1.sch Sheet: /STPMIC1_Board/sheet60878B3D/ Chris Sutton Minimum connections for STPMIC1

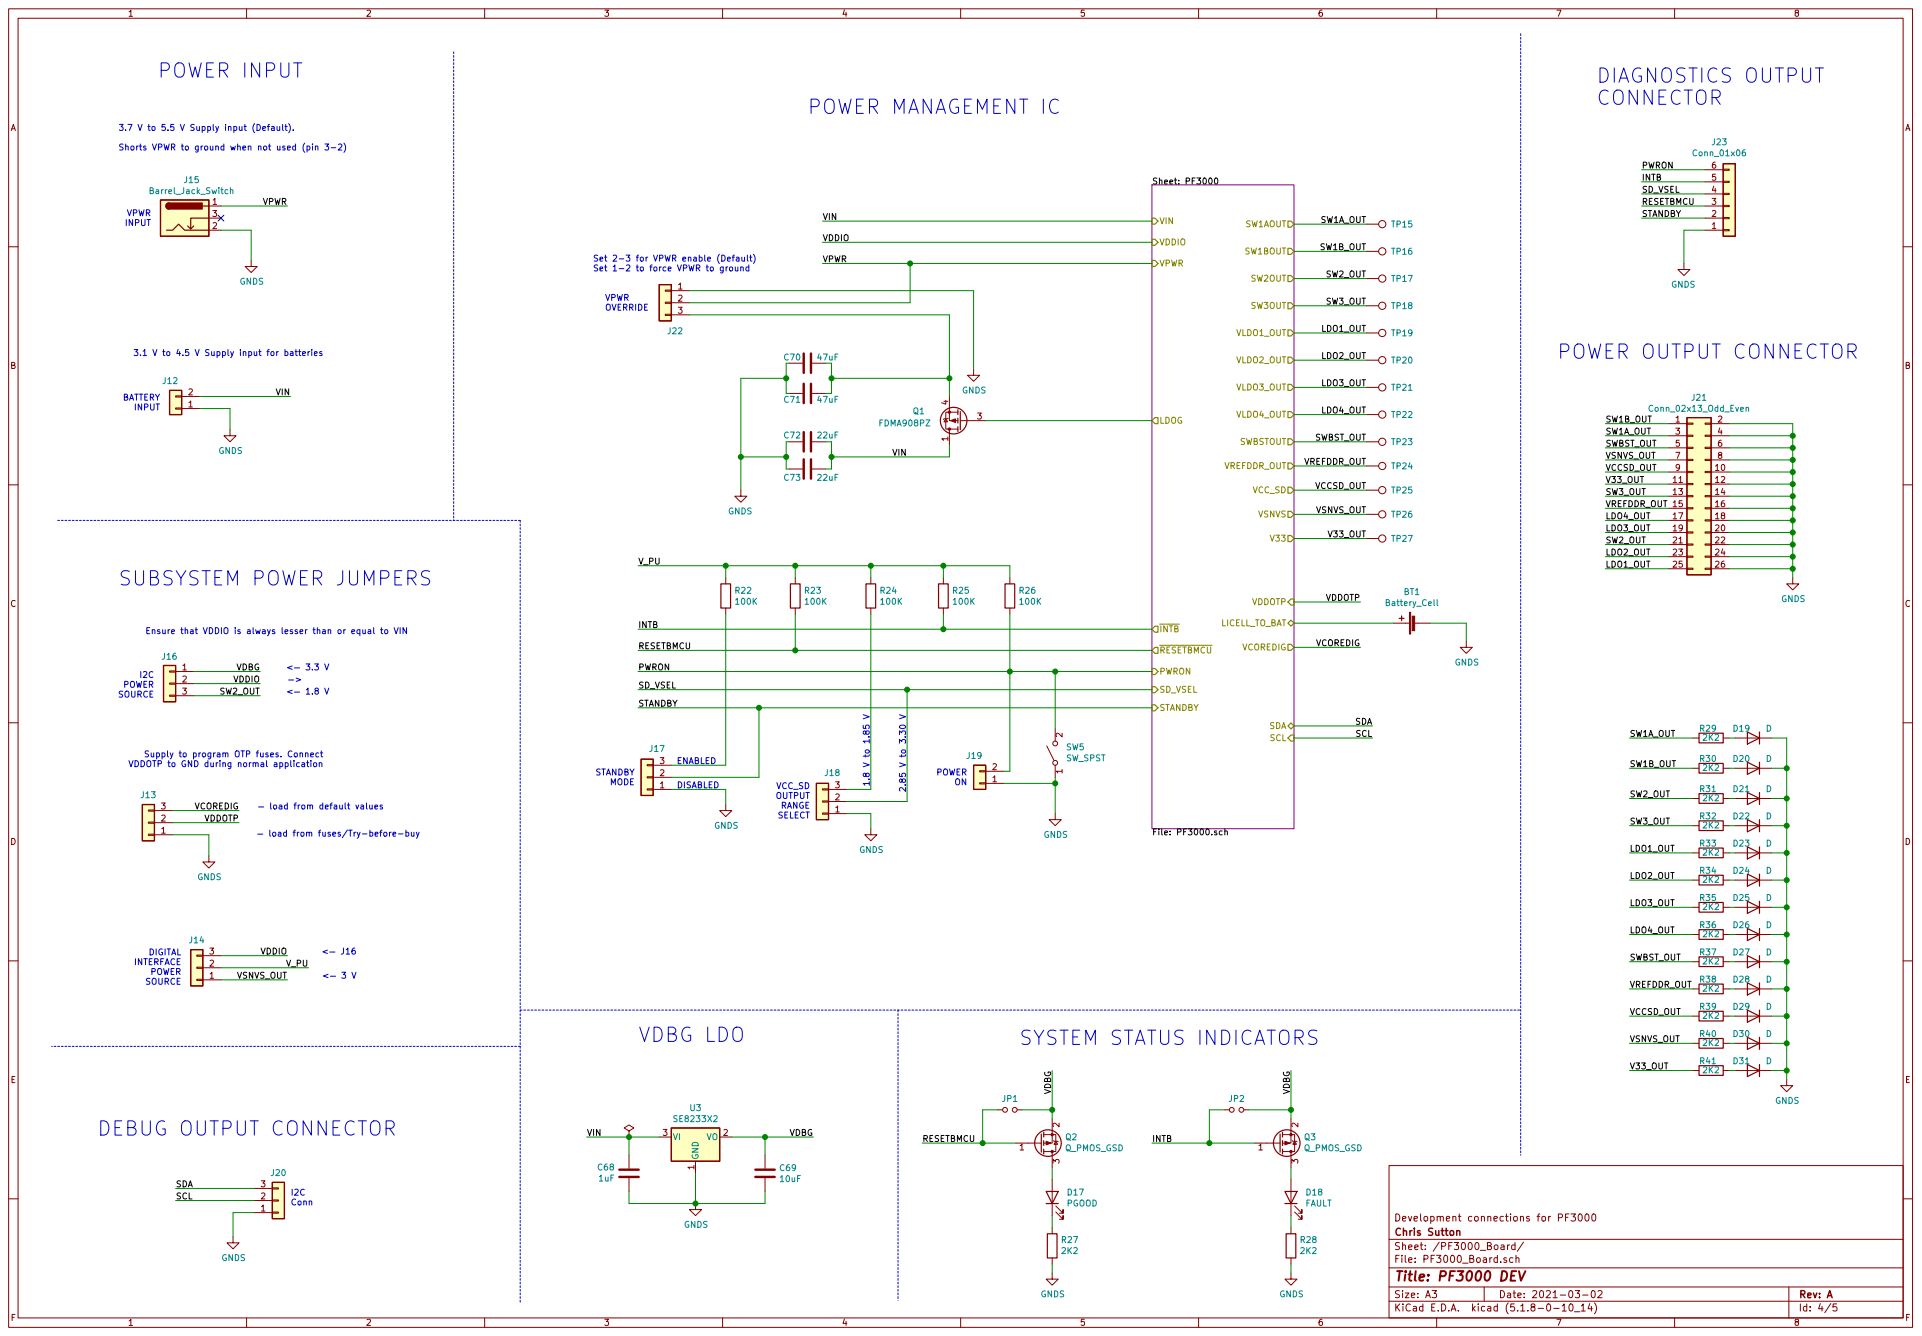
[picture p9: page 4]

CONNECTOR 1.8 V to 1.85 V STANDBY MODE

3.7 V to 5.5 V Supply input (Default).

Shorts VPWR to ground when not used (pin 3-2)

Set 1-2 to force VPWR to ground VPWR OVERRIDE

3.1 V to 4.5 V Supply input for batteries

DISABLED SUBSYSTEM POWER JUMPERS

Ensure that VDDIO is always lesser than or equal to VIN

Supply to program OTP fuses. Connect
VDDOTP to GND during normal application
POWERON DEBUG OUTPUT CONNECTOR

load from default values

load from fuses/Try-before-buy

Sheet: /PF3000_Board/ Chris Sutton Development connections for PF3000

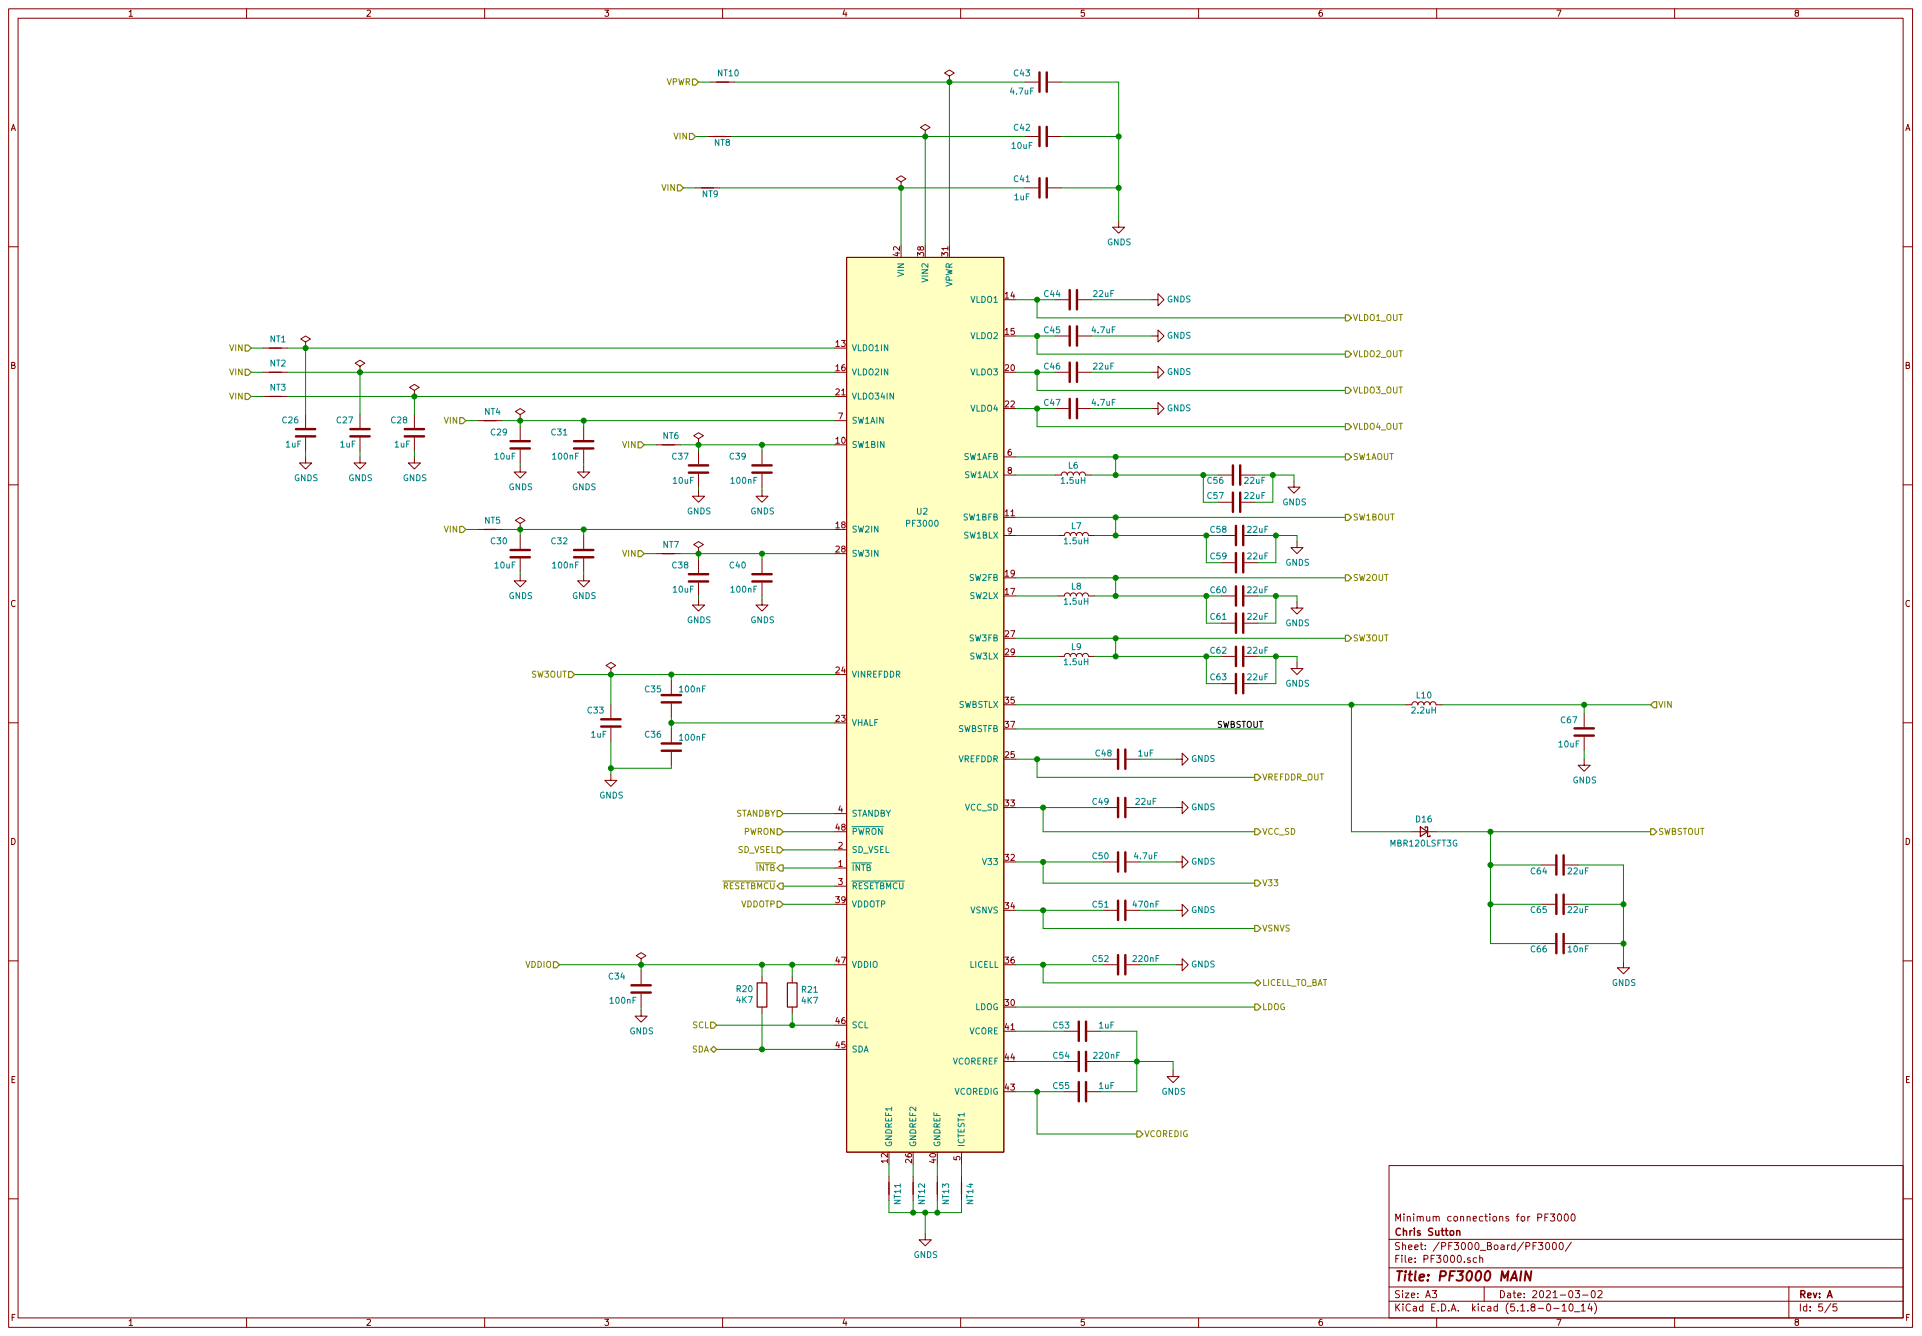
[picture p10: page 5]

File: PF3000.sch Sheet: /PF3000_Board/PF3000/ Chris Sutton Minimum connections for PF3000

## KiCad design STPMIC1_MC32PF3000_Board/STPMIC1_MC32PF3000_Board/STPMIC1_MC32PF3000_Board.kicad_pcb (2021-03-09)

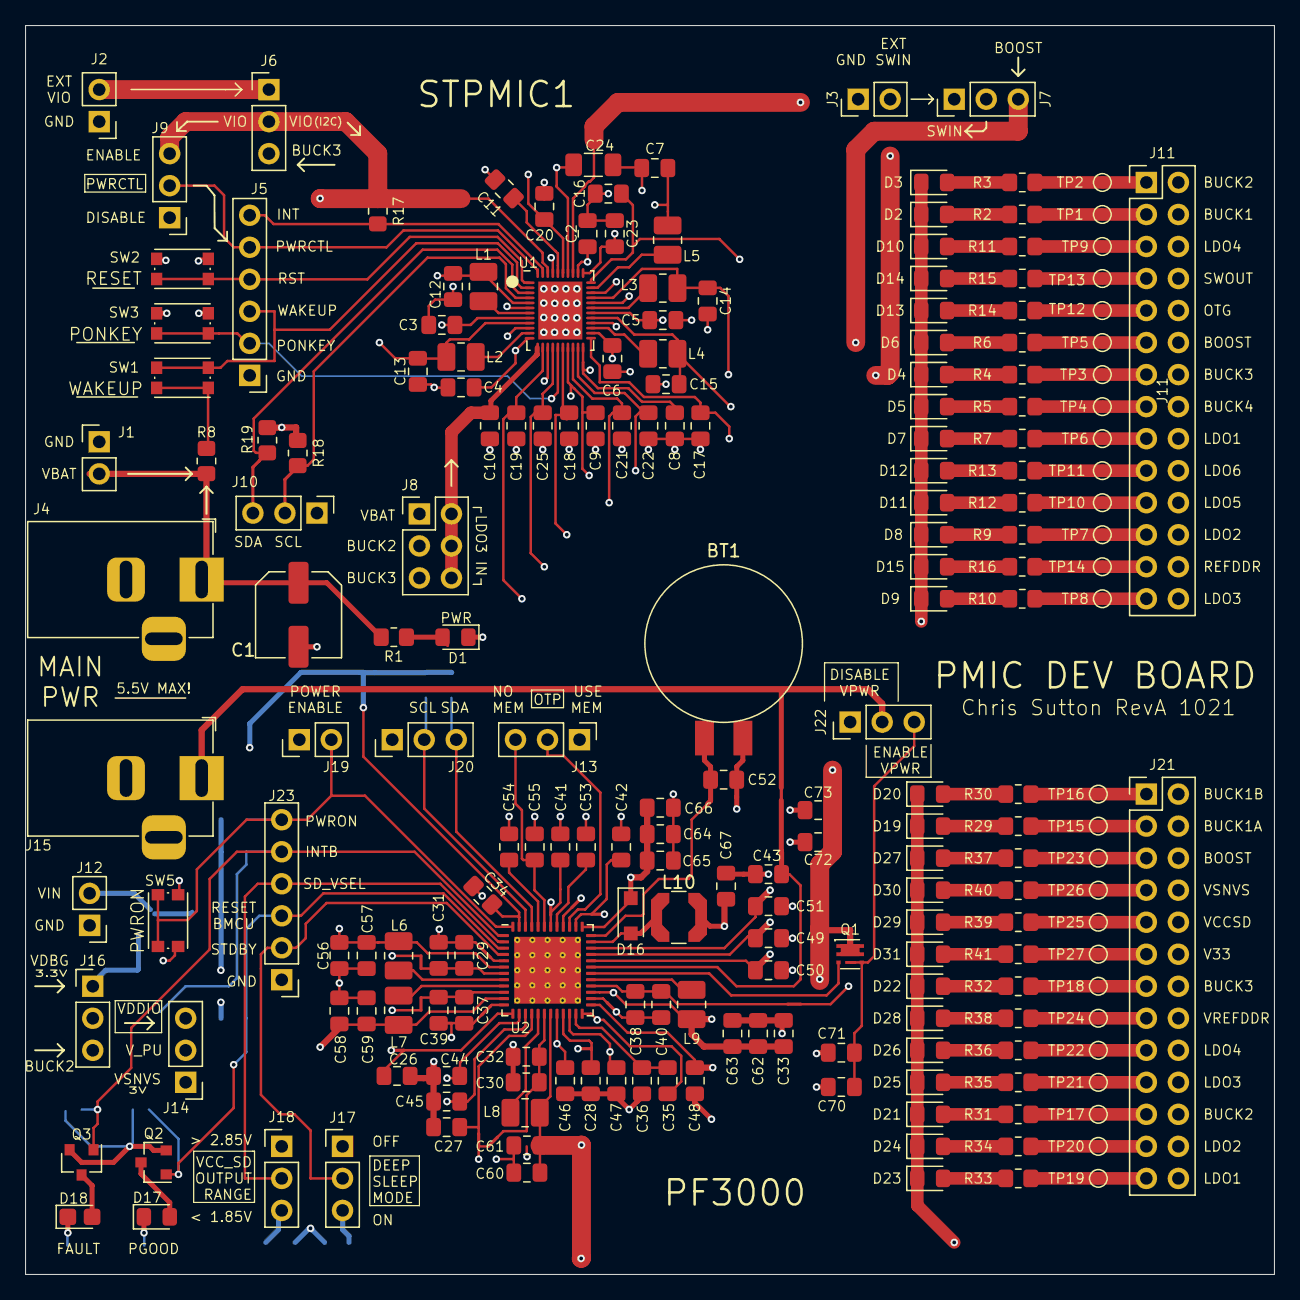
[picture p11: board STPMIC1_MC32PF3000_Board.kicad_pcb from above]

Board: 4 copper layers, 99.1 x 99.1 mm, 232 parts (0 on the bottom side), 121 nets.

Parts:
BT1: Battery_Cell; ML1220_F1BN
C1: 100uF; C_Elec_6.3x7.7
C2, C11, C17, C18, C20, C21, C22, C23, C43, C45, C47, C50: 4.7uF; C_0805_2012Metric_Pad1.18x1.45mm_HandSolder
C3, C4, C5, C6, C7, C10, C19, C29, C30, C37, C38, C42, C67, C69: 10uF; C_0805_2012Metric_Pad1.18x1.45mm_HandSolder
C8, C9, C25, C26, C27, C28, C33, C41, C48, C53, C55, C68: 1uF; C_0805_2012Metric_Pad1.18x1.45mm_HandSolder
C12, C13, C14, C15, C16, C44, C46, C49, C56, C57, C58, C59, C60, C61, C62, C63, C64, C65, C72, C73: 22uF; C_0805_2012Metric_Pad1.18x1.45mm_HandSolder
C24: 220uF; C_1206_3216Metric_Pad1.33x1.80mm_HandSolder
C31, C32, C34, C35, C36, C39, C40: 100nF; C_0805_2012Metric_Pad1.18x1.45mm_HandSolder
C51: 470nF; C_0805_2012Metric_Pad1.18x1.45mm_HandSolder
C52, C54: 220nF; C_0805_2012Metric_Pad1.18x1.45mm_HandSolder
C66: 10nF; C_0805_2012Metric_Pad1.18x1.45mm_HandSolder
C70, C71: 47uF; C_0805_2012Metric_Pad1.18x1.45mm_HandSolder
D1, D2, D3, D4, D5, D6, D7, D8, D9, D10, D11, D12, D13, D14, D15, D19, D20, D21, D22, D23, D24, D25, D26, D27, D28, D29, D30, D31: D; LED_0805_2012Metric_Pad1.15x1.40mm_HandSolder
D16: MBR120LSFT3G; D_SOD-123F
D17: PGOOD; LED_0805_2012Metric_Pad1.15x1.40mm_HandSolder
D18: FAULT; LED_0805_2012Metric_Castellated
J1, J2, J3, J12, J19: Conn_01x02; PinHeader_1x02_P2.54mm_Vertical
J4: Barrel_Jack; BarrelJack_Horizontal
J5, J23: Conn_01x06; PinHeader_1x06_P2.54mm_Vertical
J6, J7, J9, J10, J13, J14, J16, J17, J18, J20, J22: Conn_01x03; PinHeader_1x03_P2.54mm_Vertical
J8: Conn_02x03_Odd_Even; PinHeader_2x03_P2.54mm_Vertical
J11: Conn_02x14_Odd_Even; PinHeader_2x14_P2.54mm_Vertical
J15: Barrel_Jack_Switch; BarrelJack_Horizontal
J21: Conn_02x13_Odd_Even; PinHeader_2x13_P2.54mm_Vertical
JP1, JP2: Jumper_NO_Small; SolderJumper-2_P1.3mm_Open_RoundedPad1.0x1.5mm
L1, L2, L3, L4, L5: 1uH; L_1008_2520Metric_Pad1.43x2.20mm_HandSolder
L6, L7, L8, L9: 1.5uH; L_1008_2520Metric_Pad1.43x2.20mm_HandSolder
L10: 2.2uH; L_Coilcraft_LPS4018
NT1, NT2, NT3, NT4, NT5, NT6, NT7, NT8, NT9, NT10, NT11, NT12, NT13, NT14: Net-Tie_2; NetTie-2_SMD_Pad0.254mm
Q1: FDMA908PZ; Vishay_PowerPAK_SC70-6L_Single
Q2, Q3: Q_PMOS_GSD; SOT-23
R1, R2, R3, R4, R5, R6, R7, R8, R9, R10, R11, R12, R13, R14, R15, R16, R18, R19, R27, R28, R29, R30, R31, R32, R33, R34, R35, R36, R37, R38, R39, R40, R41: 2K2; R_0805_2012Metric_Pad1.20x1.40mm_HandSolder
R17: 10K; R_0805_2012Metric_Pad1.20x1.40mm_HandSolder
R20, R21: 4K7; R_0805_2012Metric_Pad1.20x1.40mm_HandSolder
R22, R23, R24, R25, R26: 100K; R_0805_2012Metric_Pad1.20x1.40mm_HandSolder
SW1, SW2, SW3, SW5: SW_SPST; SW_Push_1P1T_NO_CK_KMR2
TP1, TP2, TP3, TP4, TP5, TP6, TP7, TP8, TP9, TP10, TP11, TP12, TP13, TP14, TP15, TP16, TP17, TP18, TP19, TP20, TP21, TP22, TP23, TP24, TP25, TP26, TP27: TestPoint; TestPoint_Pad_D1.0mm
U1: STPMIC1; WQFN-44L_EP_5x6_Pitch0.4mm
U2: PF3000; QFN-48-1EP_7x7mm_P0.5mm_EP5.3x5.3mm_ThermalVias
U3: SE8233X2; SOT-23

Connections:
/PF3000_Board/INTB: J23.5, JP2.1, Q3.1, R25.2, U2.1
/PF3000_Board/LDO1_OUT: C44.2, J21.25, R33.1, TP19.1, U2.14
/PF3000_Board/LDO2_OUT: C45.2, J21.23, R34.1, TP20.1, U2.15
/PF3000_Board/LDO3_OUT: C46.2, J21.19, R35.1, TP21.1, U2.20
/PF3000_Board/LDO4_OUT: C47.2, J21.17, R36.1, TP22.1, U2.22
/PF3000_Board/PF3000/LDOG: Q1.3, U2.30
/PF3000_Board/PF3000/LICELL_TO_BAT: BT1.1, C52.2, U2.36
/PF3000_Board/PWRON: J19.2, J23.6, R26.2, SW5.2, U2.48
/PF3000_Board/RESETBMCU: J23.3, JP1.1, Q2.1, R23.2, U2.3
/PF3000_Board/SCL: J20.2, R21.2, U2.46
/PF3000_Board/SDA: J20.3, R20.1, U2.45
/PF3000_Board/SD_VSEL: J18.2, J23.4, U2.2
/PF3000_Board/STANDBY: J17.2, J23.2, U2.4
/PF3000_Board/SW1A_OUT: C56.2, C57.2, J21.3, L6.2, R29.1, TP15.1, U2.6
/PF3000_Board/SW1B_OUT: C58.2, C59.2, J21.1, L7.2, R30.1, TP16.1, U2.11
/PF3000_Board/SW2_OUT: C60.2, C61.2, J16.3, J21.21, L8.2, R31.1, TP17.1, U2.19
/PF3000_Board/SW3_OUT: C33.2, C35.2, C62.2, C63.2, J21.13, L9.2, R32.1, TP18.1, U2.24, U2.27
/PF3000_Board/SWBST_OUT: C64.2, C65.2, C66.2, D16.1, J21.5, R37.1, TP23.1, U2.37
/PF3000_Board/V33_OUT: C50.2, J21.11, R41.1, TP27.1, U2.32
/PF3000_Board/VCCSD_OUT: C49.2, J21.9, R39.1, TP25.1, U2.33
/PF3000_Board/VCOREDIG: C55.2, J13.3, U2.43
/PF3000_Board/VDBG: C69.1, J16.1, JP1.2, JP2.2, Q2.2, Q3.2, U3.2
/PF3000_Board/VDDIO: C34.2, J14.3, J16.2, R20.2, R21.1, U2.47
/PF3000_Board/VDDOTP: J13.2, U2.39
/PF3000_Board/VIN: C67.1, C68.2, C72.1, C73.2, J12.2, L10.2, NT1.1, NT2.1, NT3.1, NT4.1, NT5.1, NT6.1, NT7.1, NT8.1, NT9.1, Q1.1, U3.3
/PF3000_Board/VPWR: J15.1, J22.2, NT10.1
/PF3000_Board/VREFDDR_OUT: C48.2, J21.15, R38.1, TP24.1, U2.25
/PF3000_Board/VSNVS_OUT: C51.2, J14.1, J21.7, R40.1, TP26.1, U2.34
/PF3000_Board/V_PU: J14.2, R22.1, R23.1, R24.1, R25.1, R26.1
/STPMIC1_Board/INT: J5.6, R17.2, U1.43
/STPMIC1_Board/PONKEY: J5.2, SW3.2, U1.17
/STPMIC1_Board/PWRCTL: J5.5, J9.2, U1.44
/STPMIC1_Board/RST: J5.4, SW2.2, U1.1
/STPMIC1_Board/SCL: J10.2, R18.2, U1.4
/STPMIC1_Board/SDA: J10.3, R19.2, U1.3
/STPMIC1_Board/SWIN_Ext: J3.2, J7.1
/STPMIC1_Board/VBAT: C1.1, C2.1, C3.1, C4.1, C5.1, C6.1, C7.1, C8.1, C9.1, J1.2, J4.1, J8.1, L5.1, R1.1, R8.1, U1.8, U1.12, U1.19, U1.22, U1.24, U1.28, U1.36
/STPMIC1_Board/VBOOST: C16.1, J7.3, J11.11, R6.1, TP5.1, U1.34
/STPMIC1_Board/VBUCK1: C12.1, J11.3, L1.2, R2.1, TP1.1, U1.5
/STPMIC1_Board/VBUCK2: C13.1, J8.3, J11.1, L2.2, R3.1, TP2.1, U1.9
/STPMIC1_Board/VBUCK3: C14.1, J6.3, J8.5, J11.13, L3.2, R4.1, TP3.1, U1.31
/STPMIC1_Board/VBUCK4: C15.1, J11.15, L4.2, R5.1, TP4.1, U1.27
/STPMIC1_Board/VIO: J6.2, J9.3, R17.1, R18.1, R19.1, U1.42
/STPMIC1_Board/VIO_Ext: J2.2, J6.1
/STPMIC1_Board/VLDO1: C17.1, J11.17, R7.1, TP6.1, U1.23
/STPMIC1_Board/VLDO2: C18.1, J11.23, R9.1, TP7.1, U1.18
/STPMIC1_Board/VLDO3: C19.1, J11.27, R10.1, TP8.1, U1.14
/STPMIC1_Board/VLDO4: C20.1, J11.5, R11.1, TP9.1, U1.39
/STPMIC1_Board/VLDO5: C21.1, J11.21, R12.1, TP10.1, U1.20
/STPMIC1_Board/VLDO6: C22.1, J11.19, R13.1, TP11.1, U1.21
/STPMIC1_Board/VOTG: C23.1, J11.9, R14.1, TP12.1, U1.35
/STPMIC1_Board/VREFDDR: C25.1, J11.25, R16.1, TP14.1, U1.16
/STPMIC1_Board/VSWOUT: C24.1, J11.7, R15.1, TP13.1, U1.38
/STPMIC1_Board/WAKEUP: J5.3, SW1.1, U1.2
/STPMIC1_Board/sheet60878B3D/LDO3_IN: C10.1, J8.2, J8.4, J8.6, U1.13
/STPMIC1_Board/sheet60878B3D/VSWIN: J7.2, U1.37
GNDS: BT1.2, C1.2, C2.2, C3.2, C4.2, C5.2, C6.2, C7.2, C8.2, C9.2, C10.2, C11.2, C12.2, C13.2, C14.2, C15.2, C16.2, C17.2, C18.2, C19.2, C20.2, C21.2, C22.2, C23.2, C24.2, C25.2, C26.1, C27.1, C28.1, C29.1, C30.1, C31.1, C32.1, C33.1, C34.1, C36.1, C37.1, C38.1, C39.1, C40.1, C41.1, C42.1, C43.1, C44.1, C45.1, C46.1, C47.1, C48.1, C49.1, C50.1, C51.1, C52.1, C53.1, C54.1, C55.1, C56.1, C57.1, C58.1, C59.1, C60.1, C61.1, C62.1, C63.1, C64.1, C65.1, C66.1, C67.2, C68.1, C69.2, C70.1, C71.2, C72.2, C73.1, D1.1, D2.1, D3.1, D4.1, D5.1, D6.1, D7.1, D8.1, D9.1, D10.1, D11.1, D12.1, D13.1, D14.1, D15.1, D19.1, D20.1, D21.1, D22.1, D23.1, D24.1, D25.1, D26.1, D27.1, D28.1, D29.1, D30.1, D31.1, J1.1, J2.1, J3.1, J4.2, J5.1, J9.1, J10.1, J11.2, J11.4, J11.6, J11.8, J11.10, J11.12, J11.14, J11.16, J11.18, J11.20, J11.22, J11.24, J11.26, J11.28, J12.1, J13.1, J15.2, J17.1, J18.1, J19.1, J20.1, J21.2, J21.4, J21.6, J21.8, J21.10, J21.12, J21.14, J21.16, J21.18, J21.20, J21.22, J21.24, J21.26, J22.1, J23.1, NT11.2, NT12.2, NT13.2, NT14.2, R27.1, R28.1, SW2.1, SW3.1, SW5.1, U1.6, U1.10, U1.15, U1.26, U1.30, U1.32, U1.41, U3.1
unnamed: C11.1, U1.40
unnamed: C26.2, NT1.2, U2.13
unnamed: C27.2, NT2.2, U2.16
unnamed: C28.2, NT3.2, U2.21
unnamed: C29.2, C31.2, NT4.2, U2.7
unnamed: C30.2, C32.2, NT5.2, U2.18
unnamed: C35.1, C36.2, U2.23
unnamed: C37.2, C39.2, NT6.2, U2.10
unnamed: C38.2, C40.2, NT7.2, U2.28
unnamed: C41.2, NT9.2, U2.42
unnamed: C42.2, NT8.2, U2.38
unnamed: C43.2, NT10.2, U2.31
unnamed: C53.2, U2.41
unnamed: C54.2, U2.44
unnamed: C70.2, C71.1, J22.3, Q1.4
unnamed: D1.2, R1.2
unnamed: D2.2, R2.2
unnamed: D3.2, R3.2
unnamed: D4.2, R4.2
unnamed: D5.2, R5.2
unnamed: D6.2, R6.2
unnamed: D7.2, R7.2
unnamed: D8.2, R9.2
unnamed: D9.2, R10.2
unnamed: D10.2, R11.2
unnamed: D11.2, R12.2
unnamed: D12.2, R13.2
unnamed: D13.2, R14.2
unnamed: D14.2, R15.2
unnamed: D15.2, R16.2
unnamed: D16.2, L10.1, U2.35
unnamed: D17.1, R27.2
unnamed: D17.2, Q2.3
unnamed: D18.1, R28.2
unnamed: D18.2, Q3.3
unnamed: D19.2, R29.2
unnamed: D20.2, R30.2
unnamed: D21.2, R31.2
unnamed: D22.2, R32.2
unnamed: D23.2, R33.2
unnamed: D24.2, R34.2
unnamed: D25.2, R35.2
unnamed: D26.2, R36.2
unnamed: D27.2, R37.2
unnamed: D28.2, R38.2
unnamed: D29.2, R39.2
unnamed: D30.2, R40.2
unnamed: D31.2, R41.2
unnamed: J17.3, R22.2
unnamed: J18.3, R24.2
unnamed: L1.1, U1.7
unnamed: L2.1, U1.11
unnamed: L3.1, U1.29
unnamed: L4.1, U1.25
unnamed: L5.2, U1.33
unnamed: L6.1, U2.8
unnamed: L7.1, U2.9
unnamed: L8.1, U2.17
unnamed: L9.1, U2.29
unnamed: NT11.1, U2.12
unnamed: NT12.1, U2.26
unnamed: NT13.1, U2.40
unnamed: NT14.1, U2.5
unnamed: R8.2, SW1.2

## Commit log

2021-03-02 Added STPMIC1 and PF3000 (no layout) designs
    [750-28634_B.xls, KMR231NGULCLFS.stp, MCP16502TAC.sch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]
2021-03-02 updated schema document
    [PF3000.sch, PF3000_Board.sch, STPMIC1.sch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]
2021-03-06 Completed RevA layout
    [750-28634_B.xls, PF3000.sch, PF3000_Board.sch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]
2021-03-07 updated RevA Layout
    [PF3000_Board.sch, STPMIC1.sch, STPMIC1_Board.sch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]
2021-03-09 Completed RevA
    [750-28634_B.xls, PF3000.sch, PF3000_Board.sch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]
2021-03-09 updated readme
    Added connector and jumper/switch details
    [STPMIC1_MC32PF3000_Board_with_LCSC_Extended_Parts.csv, STPMIC1_MC32PF3000_Board_without_LCSC_Extended_Parts.csv]
2021-03-09 added full BOM csv
    [FULL_STPMIC1_MC32PF3000_Board.csv, JLCPCB_STPMIC1_MC32PF3000_Board_with_LCSC_Extended_Parts.csv, JLCPCB_STPMIC1_MC32PF3000_Board_without_LCSC_Extended_Parts.csv]
